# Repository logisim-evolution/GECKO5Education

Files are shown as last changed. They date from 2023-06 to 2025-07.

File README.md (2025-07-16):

# GECKO5Modular

The Gecko5Modular is a new take on an open hardware educational platform. The ideas
of the Gecko5Modular are based on the open hardware [ULX3S](https://github.com/emard/ulx3s) board,
the [Gecko4Education](https://gecko-wiki.ti.bfh.ch/) line of boards, and the recently developed 
[Leguan development board](https://leguan.ti.bfh.ch/).

3D preview:

TOP

This is a small (60.6x100 mm) standalone FPGA board 
for education, research and general purpose. It's open source and 
open hardware. It continues my line of educational boards used in the
past for teaching and research projects.

# Developer's guide
Detailed information how to use the board can be found [here](https://gecko5education.ti.bfh.ch).

# Production
The prototypes for these boards were produced and mounted by [Eurocircuits](https://www.eurocircuits.com/).

# Financement
The prototypes for these board (V1.0 and V1.1) were financed by the [computer architecture lab](https://www.epfl.ch/labs/lap/) of [EPFL](https://www.epfl.ch). Version V1.2 and the CPU-addon was financed by the [HuCE-microlab](https://www.bfh.ch/ti/en/research/research-areas/microlab/) of [BFH](https://www.bfh.ch).

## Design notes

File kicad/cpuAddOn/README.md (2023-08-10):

# GECKO5Education CPU-addon

This design can be used with the GECKO5Education or standalone and provides
an educational base for programming related classes.
In case this board is used with the GECKO5Education, the FTDI-chip is automatically
routed to the integrated USB-hub, meaning that you only require one USB-C connection. 
In case of this situation, the USB-C connector of the GECKO5Education is disabled, and all
functionality is provided by the USB-C connector of the CPU-addon board.

# Debugging

This board integrates a [Black Magic Probe](https://black-magic.org/index.html). After production
it needs to be programmed with the DFU-firmware once by an external programmer. After this firmware-
updates can be performed as with the normal Black Magic Probe.

# External connections

This boards integrates an extention connector (32 positions) that provides two 
[PMOD-compatible](https://digilent.com/reference/_media/reference/pmod/pmod-interface-specification-1_2_0.pdf)
interfaces. The different possibilities are listed below:

PMOD1:

|Pin|function1|function2|function3|
|:-:|:---|:---|:---|
|1  |GPIO |SPI6nCS  |I2S1_WS  |
|2  |GPIO |SPI6MOSI |I2S1_SDO |
|3  |GPIO |SPI6MISO |I2S1_SDI |
|4  |GPIO |SPI6SCK  |I2S1_CK  |
|7  |GPIO |EXTI5 | |
|8  |GPIO |EXTI6 | |
|9  |GPIO |SCL4 | |
|10 |GPIO |SDA4 | |

PMOD2:

|Pin|function1|function2|function3|
|:-:|:---|:---|:---|
|1  |GPIO |CTS2 | |
|2  |GPIO |TX2 | |
|3  |GPIO |RX2 | |
|4  |GPIO |RTS2 | |
|7  |GPIO |EXTI13 | |
|8  |GPIO |ADC1_2_3 |EXTI0 |
|9  |GPIO |ADC1_2_3 |EXTI1 |
|10 |GPIO |ADC3 |EXTI10 |

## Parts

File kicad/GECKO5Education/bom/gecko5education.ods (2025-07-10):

Id | Designator | Footprint | Quantity | Designation | digikey:
1 | C34,C33 | C_0402_1005Metric | 2 | 9pF
2 | Y1 | Crystal_SMD_2012-2Pin_2.0x1.2mm | 1 | RT2012-32.768-9-20-EXT-TR | 2151-RT2012-32.768-12.5-EXT-TRCT-ND
3 | U18 | DS1338Z-33&plus_T&R | 1 | DS1338Z-33+T&R | DS1338Z-33+T&RCT-ND
4 | BT1 | BatteryHolder_Keystone_2998_1x6.8mm | 1 | Battery_Cell | 36-2998-ND
5 | D14,D78,D100,D86,D24,D88,D6,D97,D44,D25,D26,D90,D46,D10,D33,D53,D96,D63,D7,D36,D65,D73,D83,D50,D37,D32,D29,D11,D89,D76,D112,D117,D8,D98,D94,D80,D91,D57,D48,D9,D67,D3,D12,D28,D42,D27,D77,D56,D71,D16,D114,D39,D40,D49,D105,D20,D22,D109,D41,D52,D69,D45,D2,D47,D92,D121,D58,D87,D62,D23,D61,D106,D30,D70,D4,D93,D116,D72,D119,D110,D54,D85,D43,D21,D35,D5,D81,D111,D59,D107,D38,D17,D102,D99,D118,D51,D108,D31,D19,D95,D120,D64,D74,D75,D104,D55,D68,D66,D15,D84,D103,D60,D79,D113,D18,D115,D13,D34,D101,D82 | EAST1616RGBB2 | 120 | EAST1616RGBB2 | 1080-1551-2-ND
6 | C15,C19,C16,C22,C21,C13,C10,C17,C32,C11,C31,C12,C20,C14,C18,C7,C8,C4,C3,C2,C1,C29 | C_0402_1005Metric | 22 | 0.1uf
7 | R38,R44,R37,R43,R40,R42,R39,R41 | R_0402_1005Metric | 8 | 130R
8 | R22 | R_0402_1005Metric | 1 | 1k1
9 | R89,R91,R70,R83,R80,R77,R68,R86,R73,R85,R76,R67,R82,R65,R71,R88,R79,R74,R64,R92 | R_0402_1005Metric | 20 | 698R
10 | R81,R78,R93,R66,R72,R87,R75,R84,R90,R69 | R_0402_1005Metric | 10 | 274R
11 | Q15,Q6,Q4,Q16,Q17,Q3,Q1,Q11,Q13,Q2,Q10,Q14,Q8,Q12,Q7,Q9,Q5 | SOT-23 | 17 | BC807 | BC807-25-TPMSTR-ND
12 | R24,R30,R11,R61,R46,R12,R63,R26,R62,R4,R23,R45,R1,R14,R15,R47,R29,R25,R2,R13,R16,R60,R7,R10,R28,R27 | R_0402_1005Metric | 26 | 10k
13 | U4,U5 | SOT815-1_3.5_5.5_0.85 | 2 | 74HC154BQ,118 | 1727-6583-1-ND
14 | R5 | R_0402_1005Metric | 1 | 12k
15 | U12 | LTC-4627Jx | 1 | LTC-4627JR | 160-1550-5-ND
16 | R55,R35,R48,R52,R57,R49,R54,R34,R53,R36,R50,R51,R59,R32,R6,R58,R56,R33 | R_0402_1005Metric | 18 | 1k
17 | J3 | PinSocket_1x06_P2.54mm_Horizontal | 1 | Conn_01x06_Socket | SAM1225-06-ND
18 | C25,C26,C28,C24 | C_0603_1608Metric | 4 | C1608X5R0J106M080AB | 445-4112-2-ND
19 | U13,U14 | SOT-23-5 | 2 | NCP1529A | NCP1529ASNT1GOSTR-ND
20 | X2 | Oscillator_SMD_ECS_2520MV-xxx-xx-4Pin_2.5x2.0mm | 1 | ECS-2520MV-500-BL-TR | 50-ECS-2520MV-500-BL-TRCT-ND
21 | C9 | C_0402_1005Metric | 1 | 3u3 | 399-C0402C335M7PAC7867TR-ND
22 | X3 | OSCCC700X500X180-4N | 1 | CB3LV-3I-74M2500 | 110-CB3LV-3I-74M250000CT-ND
23 | L1,L2 | INDUCTOR | 2 | LQM2HPN2R2MJ0L | 490-6700-1-ND
24 | U10 | SOT-23-5 | 1 | LP5907MFX-1.8 | 296-41463-1-ND
25 | SW6 | SW_B3U-1000P_OMR | 1 | B3U-1000P[] | SW1020CT-ND
26 | SW1,SW5,SW2,SW4,SW3 | pushbutton | 5 | SW_Push | 450-1759-1-ND
27 | C23,C27 | C_0402_1005Metric | 2 | 18p
28 | U8 | SOT-23-5 | 1 | LP5907MFX-2.5 | 296-40356-1-ND
29 | U1 | SOIC-8_3.9x4.9mm_P1.27mm | 1 | 93C46C-I/SN | 93C46C-I/SN-ND
30 | R8 | R_0402_1005Metric | 1 | 510R
31 | R117,R116 | R_0402_1005Metric | 2 | 5k1
32 | X4 | Oscillator_SMD_ECS_2520MV-xxx-xx-4Pin_2.5x2.0mm | 1 | ECS-2520MV-240-BL-TR | 50-ECS-2520MV-120-BL-TRCT-ND
33 | U17 | SOP50P490X110-11N | 1 | MAX11102AUB/V+ | MAX11102AUB/V+-ND
34 | D123,D122,D1,D124 | D_0402_1005Metric | 4 | SBA0530Q_R1_00001 | 3757-SBA0530Q_R1_00001CT-ND
35 | J2 | HDMI_A_Molex_208658-1001_Horizontal | 1 | HDMI_A | 900-2086581001CT-ND
36 | U15 | NX3DV42GU,115 | 1 | NX3DV42GU,115 | 568-12388-1-ND | NX3DV42GU,115
37 | U3 | QFP50P1200X1200X120-64N | 1 | TFP410PAP | 296-12666-ND
38 | J1 | USB_C_Receptacle_Molex_105450-0101 | 1 | USB_C_Receptacle | WM12856CT-ND
39 | R111 | R_0402_1005Metric | 1 | 150k
40 | SW9 | dipswitch | 1 | SW_DIP_x08 | 1-1825058-9-ND
41 | R18,R19,R20 | R_0402_1005Metric | 3 | 15k
42 | J4 | PinSocket_2x09_P2.54mm_Horizontal | 1 | Conn_02x09_Odd_Even | S5562-ND
43 | U6 | Lattice_caBGA-381_17.0x17.0mm_Layout20x20_P0.8mm_Ball0.4mm_Pad0.4mm_NSMD | 1 | LFE5U-85F-6BG381x | LFE5U-85F-6BG381C
44 | U11 | SOP-8_5.28x5.23mm_P1.27mm | 1 | MX25R3235FM2IL0 | 1092-1200-ND
45 | X1 | Oscillator_SMD_ECS_2520MV-xxx-xx-4Pin_2.5x2.0mm | 1 | ECS-2520MV-120-BL-TR | 50-ECS-2520MV-120-BL-TRCT-ND
46 | R112,R113 | R_0402_1005Metric | 2 | 100k
47 | U16 | SOT65P280X100-8N | 1 | LTC2632CTS8-LZ12TRMPBF | 505-LTC2632CTS8-LZ12#TRMPBFCT-ND
48 | R21 | R_0402_1005Metric | 1 | 4k7
49 | R110 | R_0402_1005Metric | 1 | 680k
50 | S1 | SW_JS5208 | 1 | JS5208 | EG4561-ND
51 | U7 | SOIC-8_5.23x5.23mm_P1.27mm | 1 | W25Q128JVS | W25Q128JVSIQCT-ND
52 | U9 | tf_bga_54L_8x8 | 1 | IS42VM16160k-75BLI | 706-1313-ND
53 | R3 | R_0402_1005Metric | 1 | 2k2
54 | U2 | QFN-64-1EP_9x9mm_P0.5mm_EP4.35x4.35mm | 1 | FT2232HQ | 768-1025-1-ND
55 | J5 | SAMTEC_QSE-020-01-X-D-A | 1 | QSE-020-01-XXX-D | 612-QSE-020-01-F-D-A-CT-ND

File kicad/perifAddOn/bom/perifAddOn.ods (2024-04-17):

Id | Designator | Footprint | Quantity | Designation | Digikey:
1 | R2,R1 | R_0402_1005Metric | 2 | 5k1
2 | C19,C20,C8,C4,C5,C23,C14,C2,C26,C6,C13,C15,C22,C1,C7,C24 | C_0402_1005Metric | 16 | 100n
3 | C16,C17 | C_0402_1005Metric | 2 | 9pF
4 | R22 | R_0402_1005Metric | 1 | 768R
5 | U5 | ESP32-C3-MINI-1_EXP | 1 | ESP32-C3-MINI-1-N4 | 1965-ESP32-C3-MINI-1-N4CT-ND
6 | SW1,SW2,SW3 | SW_B3U-1000P_OMR | 3 | B3U-1000P[] | SW1020CT-ND
7 | C21,C25 | C_0402_1005Metric | 2 | 1uF
8 | R5,R18,R10,R24,R20,R21,R4,R17,R9,R12,R3,R19,R11,R6 | R_0402_1005Metric | 14 | 10k
9 | J4 | PinHeader_2x15_P2.54mm_Horizontal | 1 | 302-R301 | ED10539-ND
10 | Y1 | Crystal_SMD_2012-2Pin_2.0x1.2mm | 1 | RT2012-32.768-9-20-EXT-TR | 2151-RT2012-32.768-9-20-EXT-TRCT-ND
11 | J2 | MOLEX_105450-0101 | 1 | 105450-0101 | WM12856CT-ND
12 | U2 | D14 | 1 | SN74HC266DR | 296-31804-1-ND
13 | R23 | R_0402_1005Metric | 1 | 330R
14 | U4 | SOT-23-5 | 1 | NCP1529A | NCP1529ASNT1GOSCT-ND
15 | R16,R15,R14 | R_0402_1005Metric | 3 | 100k
16 | C12,C11,C18,C3,C9 | C_0603_1608Metric | 5 | C1608X5R0J106M080AB | 445-4112-1-ND
17 | R7 | R_0402_1005Metric | 1 | 680k
18 | J5 | PinSocket_2x15_P2.54mm_Horizontal | 1 | PPPC152LJBN-RC | S5568-ND
19 | U7 | TSSOP20_TOS | 1 | TC7MBL3245CFTEL | TC7MBL3245CFT(EL)CT-ND
20 | L1 | LQM2HPN2R2MJ0L | 1 | LQM2HPN2R2MJ0L | 490-6700-2-ND
21 | R13 | R_0402_1005Metric | 1 | 12k
22 | J3 | AMPHENOL_GTFP08431BEU | 1 | GTFP08431BEU | GTFP08431BEUTR-ND
23 | X1 | Oscillator_SMD_ECS_2520MV-xxx-xx-4Pin_2.5x2.0mm | 1 | ECS-2520MV-240-BL-TR | 50-ECS-2520MV-240-BL-TRCT-ND
24 | D1 | LED_APHBM2012SURKCGKC | 1 | APHBM2012SURKCGKC | 754-1093-1-ND
25 | U6 | QFN36_6X6MC_MCH | 1 | USB2244-AEZG-06 | USB2244-AEZG-06-ND
26 | R8 | R_0402_1005Metric | 1 | 150k
27 | C10 | C_0402_1005Metric | 1 | 18p
28 | U3 | QFN36_6X6MC_MCH | 1 | USB2513B-AEZC | USB2513B-AEZC-ND
29 | U1 | SOT26_DIO | 1 | AP2281-3WG-7 | AP2281-3WG-7DICT-ND
30 | J1 | SAMTEC_QTE-020-01-X-D-A | 1 | QTE-020-01-X-D-A | SAM8846-ND

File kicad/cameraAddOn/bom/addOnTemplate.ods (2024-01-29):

Id | Designator | Footprint | Quantity | Designation | Digikey:
1 | J5 | PinHeader_2x04_P2.54mm_Horizontal | 1 | Conn_01x08 | 609-3344-ND
2 | U6 | SOT-23-5 | 1 | NCP1529A | NCP1529ASNT1GOSCT-ND
3 | R6 | R_0402_1005Metric | 1 | 150k
4 | R5 | R_0402_1005Metric | 1 | 680k
5 | L1 | LQM2HPN2R2MJ0L | 1 | LQM2HPN2R2MJ0L | 490-6700-1-ND
6 | C26,C13,C20,C11,C23 | C_0603_1608Metric | 5 | C1608X5R0J106M080AB | 445-4112-1-ND
7 | C17 | C_0402_1005Metric | 1 | 18p
8 | U3 | SOT26_DIO | 1 | AP2281-3WG-7
9 | J12 | USB_A_Molex_67643_Horizontal | 1 | USB_B | WM4078-ND
10 | J3 | AMPHENOL_GTFP08431BEU | 1 | GTFP08431BEU | GTFP08431BEUCT-ND
11 | C25,C8,C22,C5,C9,C16,C24,C21,C14,C12,C15,C10,C33,C32,C35,C34,C1,C4 | C_0402_1005Metric | 18 | 0.1uf
12 | C19,C6,C7,C18 | C_0402_1005Metric | 4 | 9pF
13 | R19,R21,R20 | R_0402_1005Metric | 3 | 100k
14 | Y2,Y1 | Crystal_SMD_2012-2Pin_2.0x1.2mm | 2 | RT2012-32.768-9-20-EXT-TR | 2151-RT2012-32.768-9-20-EXT-TRCT-ND
15 | R14,R34,R25,R35,R9,R17,R16,R10,R28,R11,R30,R15,R29,R27,R31 | R_0402_1005Metric | 15 | 10k
16 | R2,R1 | R_0402_1005Metric | 2 | 27R
17 | R26 | R_0402_1005Metric | 1 | 510R
18 | SW3,SW1 | SW_B3U-1000P_OMR | 2 | B3U-1000P[] | SW1020CT-ND
19 | R32 | R_0402_1005Metric | 1 | 768R
20 | C3,C2 | C_0402_1005Metric | 2 | 47pF
21 | BT1 | BatteryHolder_Keystone_1060_1x2032 | 1 | Battery_Cell | 36-1060-ND
22 | U2 | DS1338Z-33&plus_T&R | 1 | DS1338Z-33+T&R | DS1338Z-33+T&RCT-ND
23 | X1 | Oscillator_SMD_ECS_2520MV-xxx-xx-4Pin_2.5x2.0mm | 1 | ECS-2520MV-240-BL-TR | 50-ECS-2520MV-240-BL-TRCT-ND
24 | D2 | LED_APHBM2012SURKCGKC | 1 | APHBM2012SURKCGKC | 754-1093-1-ND
25 | R18 | R_0402_1005Metric | 1 | 12k
26 | U5 | ESP32-C3-MINI-1_EXP | 1 | ESP32-C3-MINI-1-N4 | 1965-ESP32-C3-MINI-1-N4CT-ND
27 | R33 | R_0402_1005Metric | 1 | 330R
28 | U4 | QFN36_6X6MC_MCH | 1 | USB2513B-AEZC | USB2513B-AEZC-CT-ND
29 | J1 | USB_Micro-AB_Molex_47590-0001 | 1 | USB_B_Micro | WM17144CT-ND
30 | R4,R3 | R_0402_1005Metric | 2 | 4k7
31 | U1 | QFN-20-1EP_4x4mm_P0.5mm_EP2.5x2.5mm | 1 | FT231XQ | 768-1128-1-ND
32 | J2 | PinSocket_2x09_P2.54mm_Horizontal | 1 | Conn_02x09_Odd_Even | S5523-ND
33 | J4 | HDMI_A_Molex_208658-1001_Horizontal | 1 | HDMI_A | 900-2086581001CT-ND
34 | U7 | QFP50P1200X1200X120-64N | 1 | SII164CTG64 | 220-2189-ND
35 | J9,J8,J7,J11 | PinHeader_1x08_P2.54mm_Vertical | 4 | Conn_01x08 | 732-5321-ND
36 | J6 | PinHeader_2x18_P2.54mm_Vertical | 1 | Conn_02x18_Odd_Even | S2011EC-18-ND

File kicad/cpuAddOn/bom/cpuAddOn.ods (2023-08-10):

Id | Designator | Footprint | Quantity | Designation | Digikey:
1 | U4 | D14 | 1 | SN74HC266DR | 296-31804-1-ND
2 | SW2,SW5,SW3,SW1,SW4 | SW_B3U-1000P_OMR | 5 | B3U-1000P | SW1020CT-ND
3 | R7,R3,R4 | R_0402_1005Metric | 3 | 100k
4 | C40,C41,C31 | C_0402_1005Metric | 3 | 2.2uF
5 | C23,C24,C25,C53,C30,C36,C29,C32,C26,C54,C21 | C_0402_1005Metric | 11 | 1uF
6 | C8,C15,C19,C46,C33,C42,C45,C44,C55,C12,C43,C9,C13,C22,C39,C48,C51,C52,C14,C20,C35,C17,C38,C50,C37,C10,C34,C6,C7,C49,C47,C11,C16,C18 | C_0402_1005Metric | 34 | 100nF
7 | R36,R40,R41,R38,R37,R42,R39,R35 | R_0402_1005Metric | 8 | 62R
8 | U10 | 21-0140L_T3255-4_MXM | 1 | MAX9867ETJ+ | MAX9867ETJ+-ND
9 | U8 | SOIC127P599X175-8N | 1 | ISO1044BD | 296-ISO1044BD-ND
10 | U7 | TSOP-II-54_22.2x10.16mm_P0.8mm | 1 | AS4C16M16SA-6TAN | 1450-1251-ND
11 | R17,R25,R18,R28,R32,R31,R30,R33,R10,R11,R16,R15,R12,R21,R24,R26,R13,R9 | R_0402_1005Metric | 18 | 10k
12 | D2,D1 | LED_APHBM2012SURKCGKC | 2 | APHBM2012SURKCGKC | 754-1093-1-ND
13 | C27,C28 | C_0402_1005Metric | 2 | 220nF
14 | U13 | PQFN50P300X250X97-14N | 1 | ICM-42605 | 1428-1152-1-ND
15 | U15 | SON65P200X240X70-6N | 1 | TCS34003FNM | TCS34003FNMCT-ND
16 | R34 | R_0402_1005Metric | 1 | 47R
17 | U9 | RVA16_2P14X2P14_TEX | 1 | TS3A227ERVAR | 296-38654-1-ND
18 | R2,R1 | R_0402_1005Metric | 2 | 5.1k
19 | U6 | LQFP-144_20x20mm_P0.5mm | 1 | STM32H743ZIT6 | 497-17721-ND
20 | C5,C1,C4,C3 | C_0603_1608Metric | 4 | C1608X5R0J106M080AB | 445-4112-1-ND
21 | J3 | PinHeader_1x05_P2.54mm_Horizontal | 1 | Conn_01x05_Pin | 2057-PH1RB-05-UA-ND
22 | R29 | R_0402_1005Metric | 1 | 2.2k
23 | R27 | TRIM_3352T-1-103LF | 1 | 3352T-1-103LF | 3352T-103LF-ND
24 | R19,R22 | R_0402_1005Metric | 2 | 768R
25 | J2 | MOLEX_105450-0101 | 1 | 105450-0101 | WM12856CT-ND
26 | L2 | L_0402_1005Metric | 1 | LRC0402CS2N2GV001T | 712-LRC0402CS2N2GV001TCT-ND
27 | R8 | R_0402_1005Metric | 1 | 12k
28 | U11 | SOT-23-5 | 1 | LP5907MFX-1.8 | 296-41463-1-ND
29 | X2 | Oscillator_SMD_ECS_2520MV-xxx-xx-4Pin_2.5x2.0mm | 1 | ECS-2520MV-080-BM-TR | 50-ECS-2520MV-080-BM-TRCT-ND
30 | J5 | TE_2311765-1 | 1 | TE_2311765-1 | 2311765-2-ND
31 | S1 | JS5208 | 1 | JS5208 | EG4561-ND
32 | L1 | LQM2HPN2R2MJ0L | 1 | LQM2HPN2R2MJ0L | 490-6700-1-ND
33 | R14 | R_0402_1005Metric | 1 | 1.5k
34 | R20,R23 | R_0402_1005Metric | 2 | 330R
35 | J4 | CUI_SJ-3551B-MSMT-TR-67 | 1 | SJ-3551B-MSMT-TR-67 | 102-6037-1-ND
36 | PS1 | RFM-0505S | 1 | RFM-0505S | 945-3159-ND
37 | BT1 | BatteryHolder_Keystone_1060_1x2032 | 1 | Keystone_1060 | 36-1060-ND
38 | U16 | HDSM-433C | 1 | HDSM-433C | 516-3498-1-ND
39 | J7 | PinSocket_2x16_P2.54mm_Horizontal | 1 | Conn_02x16_Odd_Even | S5569-ND
40 | U3 | UFQFPN-48_7X7X0P55MM | 1 | STM32F103CBU6 | 497-17381-ND
41 | SD1 | sdcard | 1 | 104031-0811 | WM6357CT-ND
42 | A1 | PQFN50P200X200X80-10N | 1 | LPS22HBTR | 497-16265-1-ND
43 | U14 | SHT4X | 1 | SHT40-AD1B-R2 | 1649-SHT40-AD1B-R2CT-ND
44 | U5 | SOT26_DIO | 1 | AP2281-3WG-7 | AP2281-3WG-7DICT-ND
45 | C2 | C_0402_1005Metric | 1 | 18pF
46 | U1 | QFN36_6X6MC_MCH | 1 | USB2513B-AEZC | USB2513B-AEZC-ND
47 | U2 | SOT-23-5 | 1 | NCP1529A | NCP1529ASNT1GOSCT-ND
48 | R6 | R_0402_1005Metric | 1 | 150k
49 | U12 | SOP-8_5.28x5.23mm_P1.27mm | 1 | MX25R3235FM2IL0 | MX25R3235FM2IL0-ND
50 | R5 | R_0402_1005Metric | 1 | 680k
51 | X1 | Oscillator_SMD_ECS_2520MV-xxx-xx-4Pin_2.5x2.0mm | 1 | ECS-2520MV-240-BL-TR | 50-ECS-2520MV-240-BL-TRCT-ND
52 | J1 | SAMTEC_QTE-020-01-X-D-A | 1 | QTE-020-01-F-D-A | SAM8846-ND
53 | Y1 | Crystal_SMD_0603-2Pin_6.0x3.5mm | 1 | RT2012-32.768-9-20-EXT-TR | 2151-RT2012-32.768-9-20-EXT-TRCT-ND
54 | C57,C56 | C_0402_1005Metric | 2 | 9pF

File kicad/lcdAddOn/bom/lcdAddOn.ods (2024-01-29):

Id | Designator | Footprint | Quantity | Designation | Digikey:
1 | U1 | SSOP20_MC_MCH | 1 | AR1021-I/SS | AR1021-I/SS-ND
2 | C3 | C_0402_1005Metric | 1 | 100nF
3 | R4,R2,R3,R1 | R_0402_1005Metric | 4 | 2E
4 | R5 | R_0402_1005Metric | 1 | 20k
5 | C2,C1 | C_0402_1005Metric | 2 | 10pF
6 | J2 | CONN_62684-402100ALF_AMP | 1 | 62684-402100ALF | 609-1200-1-ND
7 | J1 | SAMTEC_QTE-020-01-X-D-A | 1 | QTE-020-01-F-D-A | SAM8846-ND
8 | SW1,SW2,SW3 | pushbutton | 3 | SW_Push | 450-1759-1-ND

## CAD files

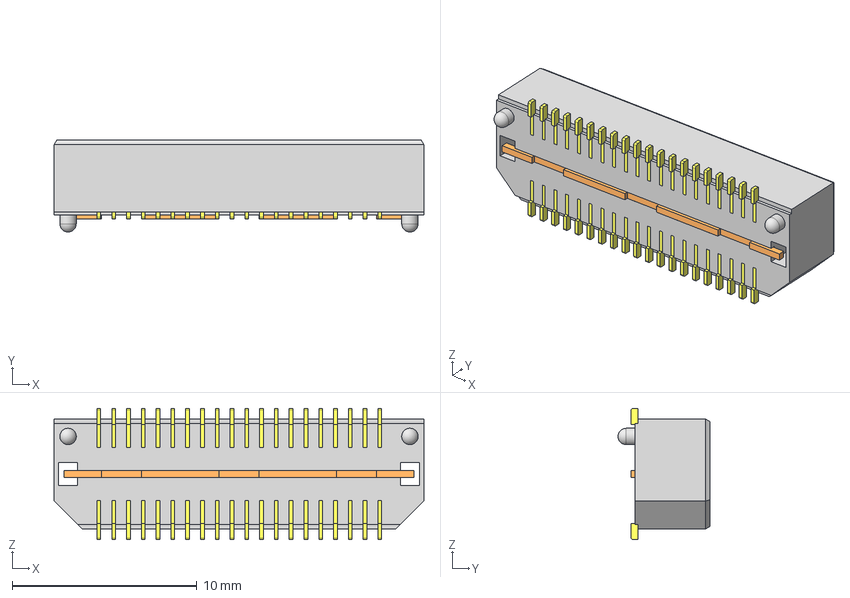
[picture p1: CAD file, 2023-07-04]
kicad/cameraAddOn/3DModels/QTE-020-01-X-D-A.step
20.0 x 4.98 x 7.11 mm
QTE-T-1G1-01_imp
PT-1S39-01(020-01-D)
QTE-020-01-D-At

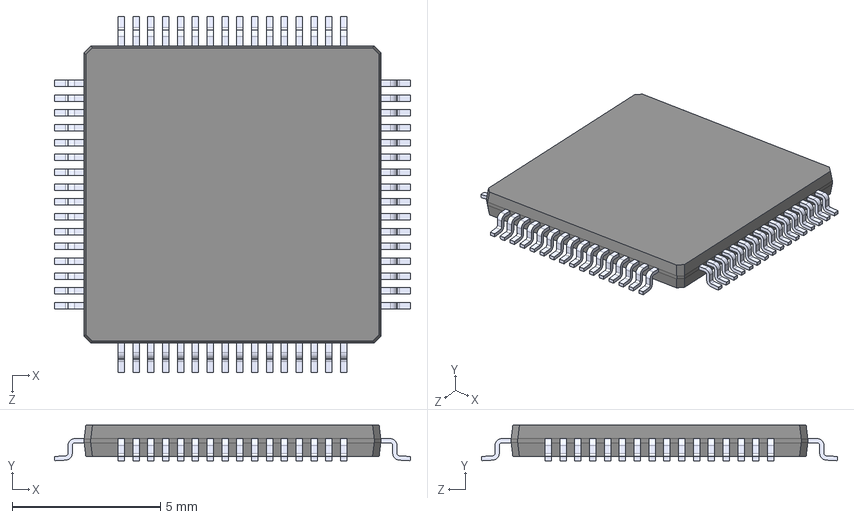
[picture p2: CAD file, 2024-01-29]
kicad/GECKO5Education/3DModels/ATSAMD51J20A-AU.STEP
12.0 x 1.20 x 12.0 mm

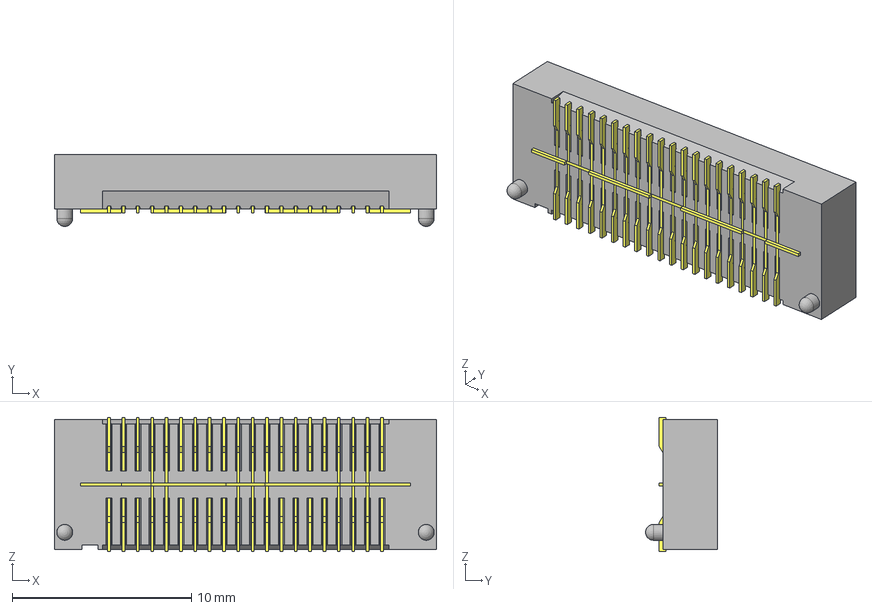
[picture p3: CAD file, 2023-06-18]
kicad/GECKO5Education/QSE-020-01-F-D-A.stp
21.3 x 4.01 x 7.49 mm
QSE-C-126-21-020-D-S
QSE-T-1G2-01-020
QSE-020-01-F-D-A-S_terminal

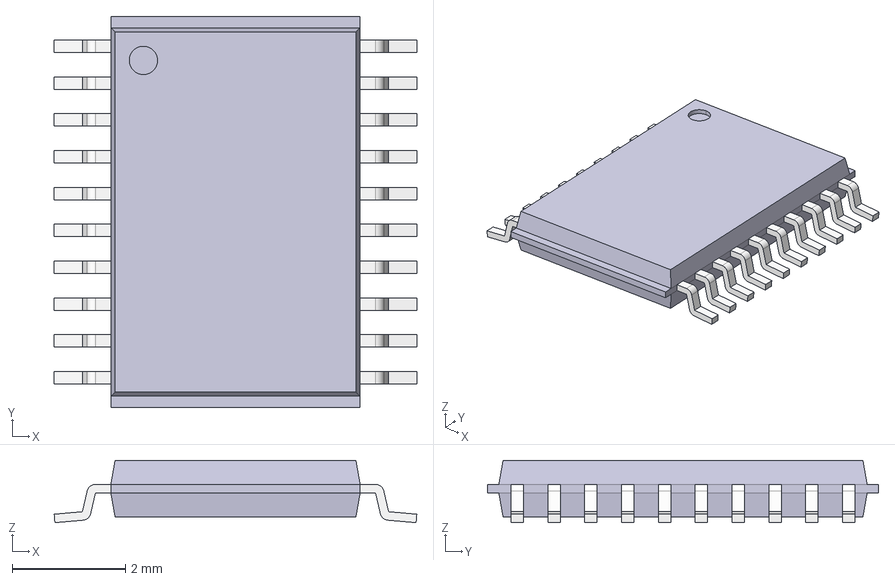
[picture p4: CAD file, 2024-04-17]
kicad/perifAddOn/3DModels/TSSOP20_z90.stp
6.40 x 6.90 x 1.10 mm

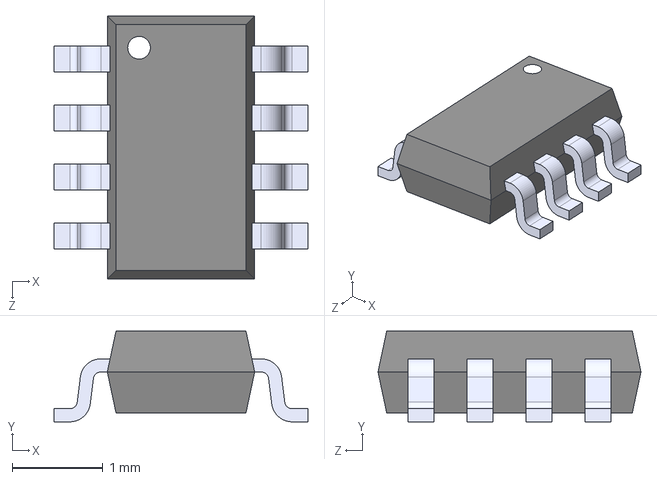
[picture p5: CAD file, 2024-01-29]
kicad/GECKO5Education/3DModels/LTC2632CTS8-LZ12#TRMPBF.STEP
2.80 x 1.00 x 2.90 mm

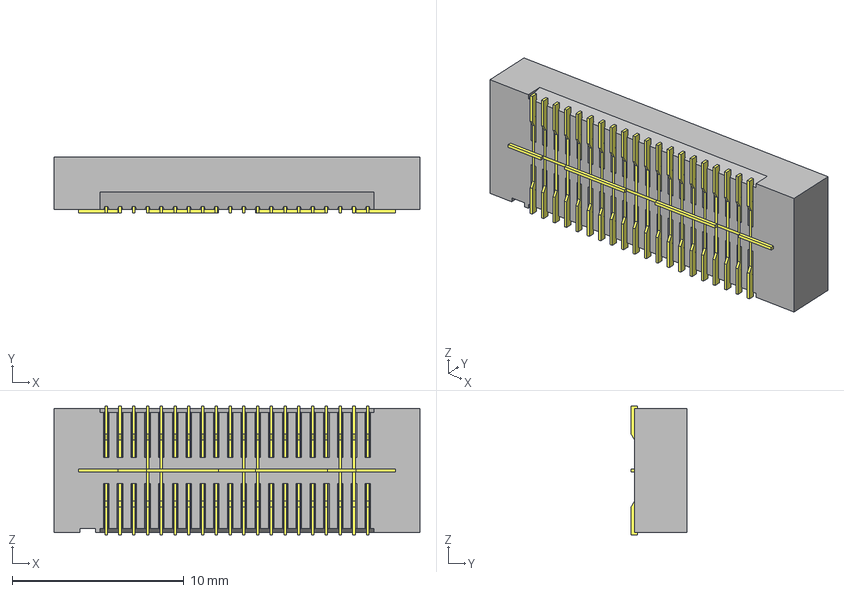
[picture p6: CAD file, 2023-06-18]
kicad/GECKO5Education/QSE-020-01-F-D.stp
21.3 x 3.25 x 7.49 mm
QSE-C-126-21-020-D-S
QSE-T-1G2-01-020
QSE-020-01-F-D-S_terminal

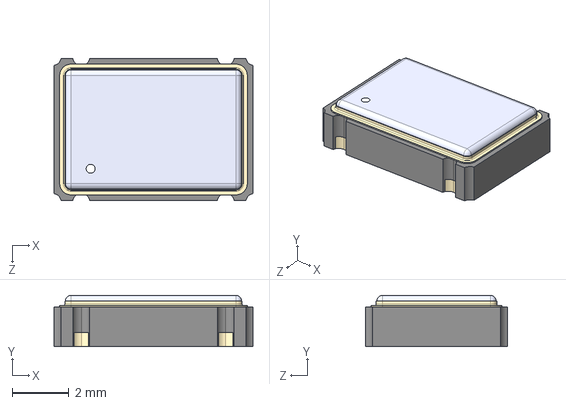
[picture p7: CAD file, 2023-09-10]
kicad/GECKO5Education/3DModels/CB3LV-3I-74M2500.step
7.00 x 1.80 x 5.00 mm

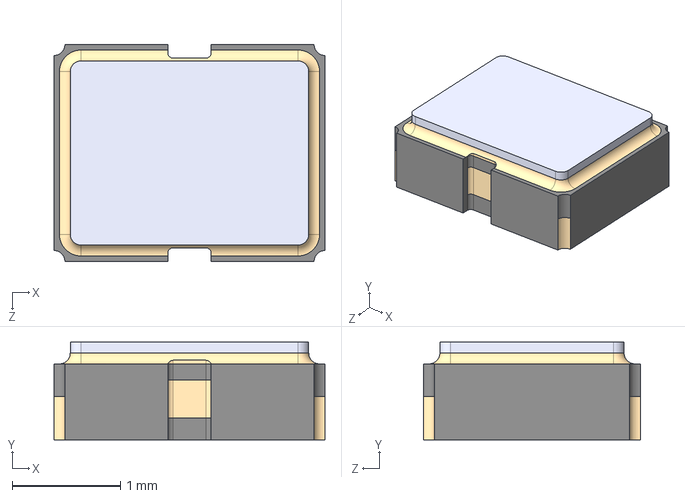
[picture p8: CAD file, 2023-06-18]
kicad/GECKO5Education/3DModels/ECS-2520MV-500-BL-TR--3DModel-STEP-269445.STEP
2.50 x 0.9 x 2.00 mm

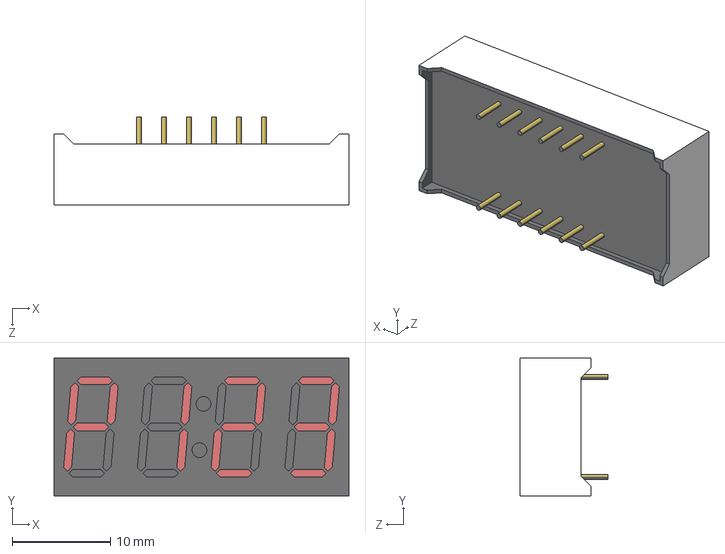
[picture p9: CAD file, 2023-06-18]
kicad/GECKO5Education/3DModels/7 segment1.STEP
30.0 x 14.0 x 8.93 mm

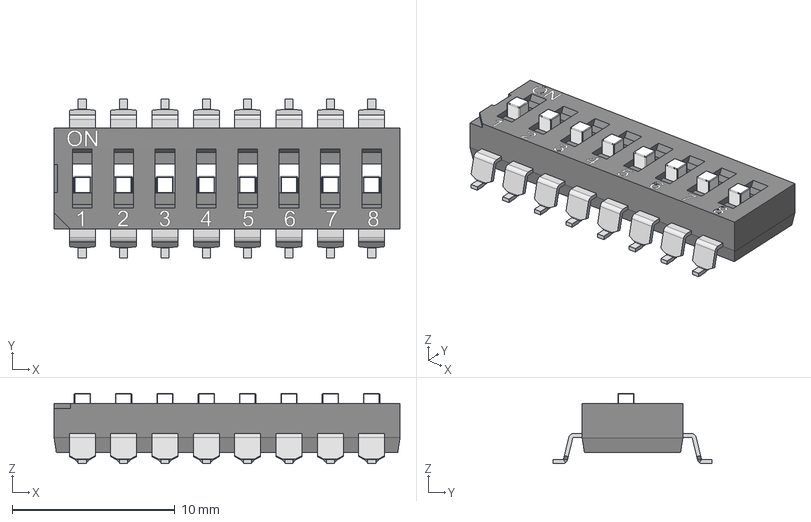
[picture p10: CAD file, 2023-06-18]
kicad/GECKO5Education/3DModels/SMD DIP SWITCH 8P.step
21.3 x 9.80 x 4.32 mm

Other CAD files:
kicad/perifAddOn/3DModels/XZCMEDGCBD110W--3DModel-STEP-56544.STEP
kicad/perifAddOn/3DModels/APHBM2012LSURKCGKC--3DModel-STEP-56544.STEP
kicad/perifAddOn/3DModels/QTE-020-01-X-D-A.step
kicad/perifAddOn/3DModels/D0014A.stp
kicad/perifAddOn/3DModels/21-0140L_T3255-4_MXM.step
kicad/perifAddOn/3DModels/2998TR--3DModel-STEP-630548.STEP
kicad/GECKO5Education/3DModels/1054500101.stp
kicad/GECKO5Education/3DModels/MAX11666AUB_V+.STEP
kicad/GECKO5Education/3DModels/QFN_H-56Q-TRAY_FTD.step
kicad/cpuAddOn/3DModels/104031-0811.stp
kicad/cpuAddOn/3DModels/105450-0101.step
kicad/cpuAddOn/3DModels/21-0140L_T3255-4_MXM.step
kicad/cpuAddOn/3DModels/2311765-1.stp
kicad/cpuAddOn/3DModels/2998TR--3DModel-STEP-630548.STEP
kicad/cpuAddOn/3DModels/3352T-1-103LF.step
kicad/cpuAddOn/3DModels/APHBM2012LSURKCGKC--3DModel-STEP-56544.STEP
kicad/cpuAddOn/3DModels/B0505S-1WR2.step
kicad/cpuAddOn/3DModels/D0014A.stp
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

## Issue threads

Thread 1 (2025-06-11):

[Feature suggestion] Providing the LPF constraints file

CyberFox001, 2025-06-11:
Hello,

First, a big thanks for your magnificent board.

As this board use the `LFE5U-85F` FPGA, it would be nice to provide the LPF constraints file adapted to the GECKO5Education board.
It would let users use the `nextpnr-ecp5` and the OSS CAD Suite to build a bitstream for the GECKO5Education.

BFH-ktt1, 2025-06-11:
Here you go:
[gecko5.zip](https://github.com/user-attachments/files/20685172/gecko5.zip)

By the way, you can also mount smaller ecp5's, the board is designed to be pin-compatable.

CyberFox001, 2025-06-11:
Thank you. Does the GECKO5Education pin-compatible with the ULX3S ?

CyberFox001, 2025-06-12:
Are you the author of this constraint file ? What are its license ?

BFH-ktt1, 2025-06-12:
> Are you the author of this constraint file ? What are its license ?

Yes, and you can use it as you like (so no license), of course with no guarantee, etc. etc.
I give it as template to my students that are working on the board.

CyberFox001, 2025-06-15:
Ok. Thank you very much.

I have seen a small mistake in the constraint file:
- The output `rgbRow` control the column in the LED matrix
- It's the outputs `red`, `green` and `blue` who control rows of the LED matrix

At least, from what I can see on the electronic schematics and on the printed circuit.

PS: I'm making my diploma work on the Gecko5Education.

BFH-ktt1, 2025-07-28:
@CyberFox001 , in a sense you are right. It all depends from which side you look at it. When we look at pin T1, from the FPGA this is the Rx, however, from the FTDI it is the Tx. This is a standard point for confusion. I would be very interested if you have some idea how to "fix" this.

CyberFox001, 2025-07-28:
As we use the inputs names of the constraint file in a HDL circuit, it make sense to use the FPGA point of view. I think.

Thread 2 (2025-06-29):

In the README, link to Gecko4Eudacation is not publicly reachable

CyberFox001, 2025-06-29:
Hello,

In the README, their is a link to the Gecko4Education line of beard. But when I follow this link, I get an error message:

> Forbidden
> Please connect to the BFH VPN service to access this resource.

maehne, 2025-06-30:
Indeed, we are aware of the problem. The documentation site is currently only reachable to students and collaborators of BFH. The documentation needs to be migrated to a new platform. Unfortunately, this effort is currently stalled due to limited resources.

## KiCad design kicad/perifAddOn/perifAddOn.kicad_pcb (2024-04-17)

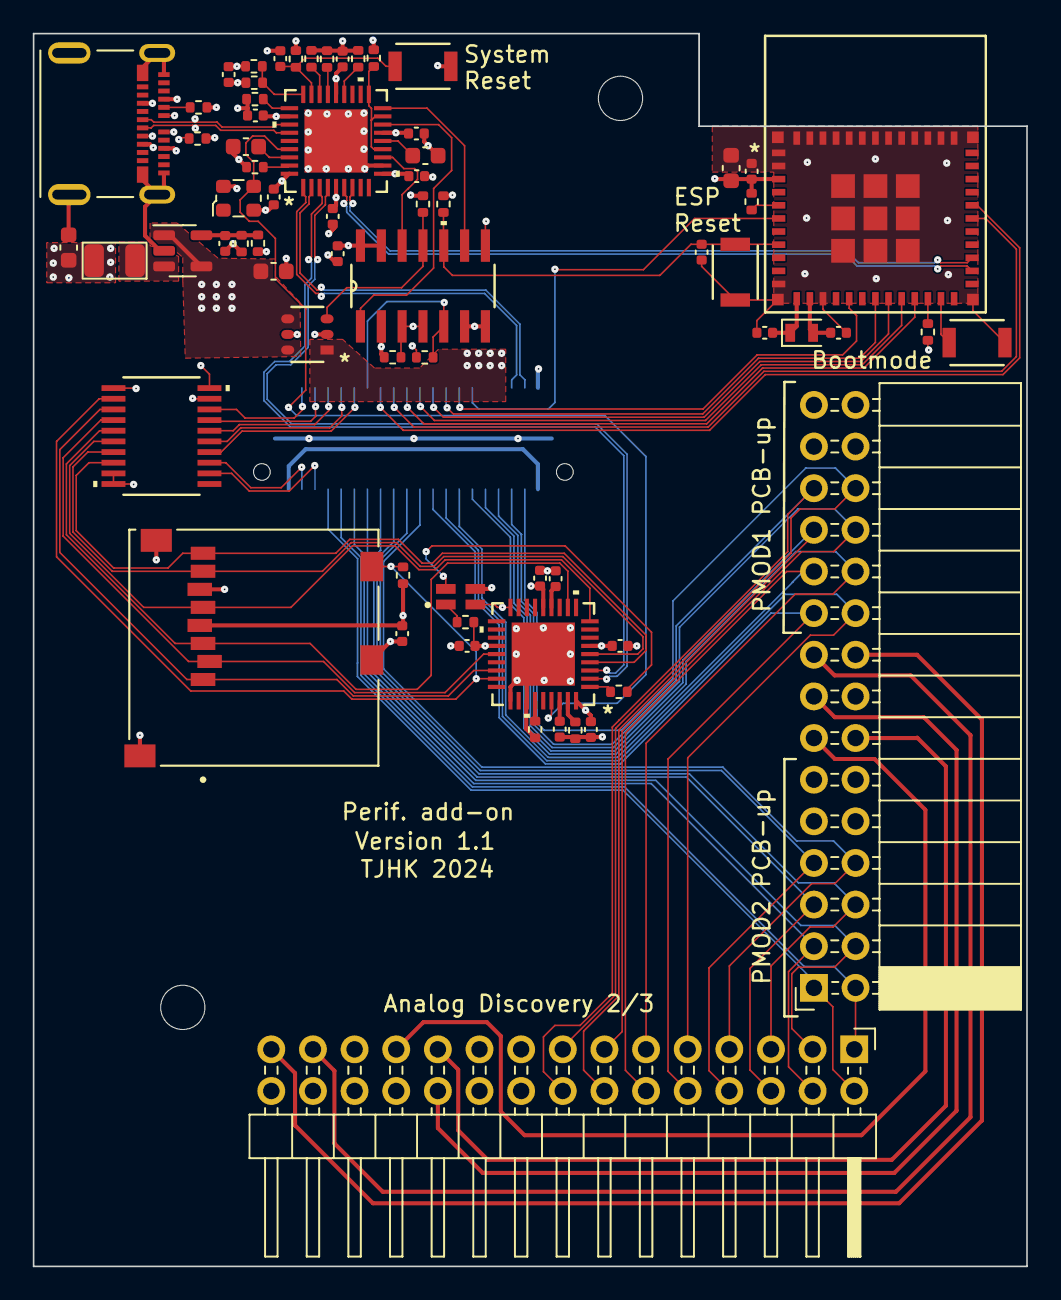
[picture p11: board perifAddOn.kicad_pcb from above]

Board: 4 copper layers, 60.6 x 75.2 mm, 69 parts (1 on the bottom side), 90 nets.

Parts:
C1, C2, C4, C5, C6, C7, C8, C13, C14, C15, C19, C20, C22, C23, C24, C26: 100n; C_0402_1005Metric
C3, C9, C11, C12, C18: C1608X5R0J106M080AB; C_0603_1608Metric
C10: 18p; C_0402_1005Metric
C16, C17: 9pF; C_0402_1005Metric
C21, C25: 1uF; C_0402_1005Metric
D1: APHBM2012SURKCGKC; LED_APHBM2012SURKCGKC
J1: QTE-020-01-X-D-A; SAMTEC_QTE-020-01-X-D-A
J2: 105450-0101; MOLEX_105450-0101
J3: GTFP08431BEU; AMPHENOL_GTFP08431BEU
J4: Conn_02x15_Odd_Even; PinHeader_2x15_P2.54mm_Horizontal
J5: Conn_02x15_Odd_Even; PinSocket_2x15_P2.54mm_Horizontal
L1: LQM2HPN2R2MJ0L
R1, R2: 5k1; R_0402_1005Metric
R3, R4, R5, R6, R9, R10, R11, R12, R17, R18, R19, R20, R21, R24: 10k; R_0402_1005Metric
R7: 680k; R_0402_1005Metric
R8: 150k; R_0402_1005Metric
R13: 12k; R_0402_1005Metric
R14, R15, R16: 100k; R_0402_1005Metric
R22: 768R; R_0402_1005Metric
R23: 330R; R_0402_1005Metric
SW1, SW2, SW3: B3U-1000P[]; SW_B3U-1000P_OMR
U1: AP2281-3WG-7; SOT26_DIO
U2: SN74HC266DR; D14
U3: USB2513B-AEZC; QFN36_6X6MC_MCH
U4: NCP1529A; SOT-23-5
U5: ESP32-C3-MINI-1-N4; ESP32-C3-MINI-1_EXP
U6: USB2244-AEZG-06; QFN36_6X6MC_MCH
U7: TC7MBL3245CFTEL; TSSOP20_TOS
X1: ECS-2520MV-240-BL-TR; Oscillator_SMD_ECS_2520MV-xxx-xx-4Pin_2.5x2.0mm
Y1: RT2012-32.768-9-20-EXT-TR; Crystal_SMD_2012-2Pin_2.0x1.2mm

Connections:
+3.3V: C1.1, C2.1, C4.1, C5.1, C6.1, C7.1, C8.1, C10.1, C11.1, C15.2, C18.1, C20.2, C22.1, C23.1, C24.1, C26.1, J3.4 (VDD), J5.11, J5.12, J5.29, J5.30, L1.2, R3.2, R4.1, R5.1, R6.2, R7.1, R16.2, R17.2, R18.2, R19.2, R22.1, U2.2 (1B), U2.8 (3A), U2.13 (4B), U2.14 (VCC), U3.5 (VDDA33), U3.10 (VDDA33), U3.15 (VDD33), U3.23 (VDD33), U3.29 (VDDA33), U3.36 (VDD33), U5.3 (3V3), U6.6 (VDD33), U6.14 (VDD33), U6.22 (VDD33), U6.36 (VDDA33), U7.20, X1.4 (VDD)
+5V: C9.1, C13.1, J2.A4 (VBUS1), J2.A9 (VBUS2), J2.B4 (VBUS3), J2.B9 (VBUS4), R14.2, U1.4 (IN), U1.6 (IN), U4.1 (EN), U4.4 (VIN)
ADC_ChanA: J4.21, J5.14
ADC_ChanB: J4.22, J5.15
Clock24MHz: U3.33 (XTALIN/CLKIN), U6.33 (XTAL1(CLKIN)), X1.3 (OUT)
D1+: J2.A6 (D1+), J2.B6 (D2+), U3.31 (USBDP_UP)
D1-: J2.A7 (D1-), J2.B7 (D2-), U3.30 (USBDM_UP)
DAC_ChanA: J4.27, J5.17
DAC_ChanB: J4.29, J5.18
ESP32Drive: U2.9 (3B), U3.18 (PRTPWR3/BC_EN3)
EnFPGA: R4.2, U1.3 (EN), U2.11 (4Y)
EspD+: U3.7 (USBDP_DN3/PRT_DIS_P3), U5.27 (IO19)
EspD-: U3.6 (USBDM_DN3/PRT_DIS_M3), U5.26 (IO18)
EspEnable: C19.1, R5.2, SW2.1, U2.10 (3Y), U5.8 (EN)
EspIO3: J1.30, U5.6 (IO3)
EspIO4: J1.26, U5.18 (IO4)
EspIO5: J1.24, U5.19 (IO5)
EspIO6: J1.22, U5.20 (IO6)
EspIO7: J1.20, U5.21 (IO7)
EspIO10: J1.28, U5.16 (IO10)
EspRxd: J1.18, U5.30 (RXD0)
EspTxd: J1.16, U5.31 (TXD0)
FPGADrive: U2.12 (4A), U3.12 (PRTPWR1/BC_EN1)
GND: C1.2, C2.2, C3.2, C4.2, C5.2, C6.2, C7.2, C8.2, C9.2, C11.2, C12.2, C13.2, C14.2, C15.1, C16.2, C17.2, C18.2, C19.2, C20.1, C21.2, C22.2, C23.2, C24.2, C25.2, C26.2, D1.3, J1.40, J1.G1 (GND), J1.G2 (GND), J1.G3 (GND), J1.G4 (GND), J2.A1 (GND1), J2.A12 (GND2), J2.B1 (GND3), J2.B12 (GND4), J2.S1 (SHIELD), J2.S2 (SHIELD), J2.S3 (SHIELD), J2.S4 (SHIELD), J3.6 (VSS), J3.G1 (SHIELD_GND), J3.G2 (SHIELD_GND__1), J3.G3 (SHIELD_GND__2), J4.19, J4.20, J4.24, J4.25, J4.26, J4.28, J4.30, J5.9, J5.10, J5.16, J5.27, J5.28, R1.1, R2.1, R8.2, R9.1, R10.1, R11.1, R12.1, R13.1, R15.1, R20.2, R21.2, R24.2, SW1.2, SW2.2, SW3.2, U1.2 (GND), U1.5 (GND), U2.6 (2B), U2.7 (GND), U3.11 (TEST), U3.37 (EPAD), U4.2 (GND), U5.1 (GND), U5.2 (GND), U5.11 (GND), U5.14 (GND), U5.36 (GND), U5.37 (GND), U5.38 (GND), U5.39 (GND), U5.40 (GND), U5.41 (GND), U5.42 (GND), U5.43 (GND), U5.44 (GND), U5.45 (GND), U5.46 (GND), U5.47 (GND), U5.48 (GND), U5.49 (GND), U5.50 (GND), U5.51 (GND), U5.52 (GND), U5.53 (GND), U5.54 (GND), U5.55 (GND), U5.56 (GND), U5.57 (GND), U5.58 (GND), U5.59 (GND), U5.60 (GND), U5.61 (GND), U6.28 (TEST), U6.30 (SD_WP), U6.37 (EPAD), U7.1, U7.9, U7.10, X1.2 (GND)
unnamed: D1.1, R22.2
unnamed: D1.4, R23.2
unnamed: J1.01, J1.39
unnamed: J2.A5 (CC1), R1.2
unnamed: J2.B5 (CC2), R2.2
unnamed: J1.32, J1.34, U1.1 (OUT)
unnamed: C3.1, U3.14 (CRFILT)
unnamed: R10.2, U3.25 (HS_IND/CFG_SEL1)
unnamed: R6.1, U3.13 (OCS_N1), U3.17 (OCS_N2), U3.19 (OCS_N3)
unnamed: C12.1, U3.34 (PLLFILT)
unnamed: R13.2, U3.35 (RBIAS)
unnamed: C14.1, R16.1, SW1.1, U3.26 (RESET_N)
unnamed: R11.2, U3.24 (SCL/SMBCLK/CFG_SEL0)
unnamed: R12.2, U3.22 (SDA/SMBDATA/NON_REM1)
unnamed: R9.2, U3.28 (SUSP_IND/LOCAL_PWR/NON_REM0)
unnamed: R14.1, R15.2, U3.27 (VBUS_DET)
unnamed: C10.2, R7.2, R8.1, U4.5 (FB)
unnamed: L1.1, U4.3 (SW)
unnamed: C17.1, U5.12 (IO0), Y1.1
unnamed: C16.1, U5.13 (IO1), Y1.2
unnamed: R17.1, U5.5 (IO2)
unnamed: R18.1, U5.22 (IO8)
unnamed: SW3.1, U5.23 (IO9)
unnamed: R23.1, U6.1 (LED)
unnamed: R21.1, U6.35 (RBIAS)
unnamed: R20.1, U6.31 (TXD/SCK)
unnamed: C25.1, U6.13 (VDD18)
unnamed: C21.1, U6.34 (VDD18PLL)
PMOD1_1: J1.23, J4.10, J5.19
PMOD1_2: J1.27, J4.12, J5.21
PMOD1_3: J1.31, J4.14, J5.23
PMOD1_4: J1.35, J4.16, J5.25
PMOD1_7: J1.25, J4.9, J5.20
PMOD1_8: J1.29, J4.11, J5.22
PMOD1_9: J1.33, J4.13, J5.24
PMOD1_10: J1.37, J4.15, J5.26
PMOD2_1: J1.07, J4.2, J5.1
PMOD2_2: J1.11, J4.4, J5.3
PMOD2_3: J1.15, J4.6, J5.5
PMOD2_4: J1.19, J4.8, J5.7
PMOD2_7: J1.09, J4.1, J5.2
PMOD2_8: J1.13, J4.3, J5.4
PMOD2_9: J1.17, J4.5, J5.6
PMOD2_10: J1.21, J4.7, J5.8
SDCReset: J1.14, R24.1, U2.5 (2A)
SDCnReset: D1.2, R3.1, U2.3 (1Y), U2.4 (2Y), U6.18 (RESET_N), U7.19
SDCnResetDrive: U2.1 (1A), U3.16 (PRTPWR2/BC_EN2)
SdClk: J3.5 (CLK), U6.9 (SD_CLK), U7.6
SdClkB: J1.12, U7.14
SdCmd: J3.3 (CMD), U6.11 (SD_CMD), U7.5
SdCmdB: J1.10, U7.15
SdD0: J3.7 (DAT0), U6.5 (SD_D0), U7.7
SdD0B: J1.03, U7.13
SdD1: J3.8 (DAT1), U6.4 (SD_D1), U7.8
SdD1B: J1.05, U7.12
SdD2: J3.1 (DAT2), U6.25 (SD_D2), U7.3
SdD2B: J1.06, U7.17
SdD3: J3.2 (CD/DAT3), U6.23 (SD_D3), U7.4
SdD3B: J1.08, U7.16
SdcD+: U3.4 (USBDP_DN2/PRT_DIS_P2), U6.2 (USB+)
SdcD-: U3.3 (USBDM_DN2/PRT_DIS_M2), U6.3 (USB-)
SdnDet: J3.CD_PIN, R19.1, U6.26 (SD_NCD), U7.2
SdnDetB: J1.04, U7.18
UsbD+: J1.38, U3.2 (USBDP_DN1/PRT_DIS_P1)
UsbD-: J1.36, U3.1 (USBDM_DN1/PRT_DIS_M1)
VREF: J4.23, J5.13

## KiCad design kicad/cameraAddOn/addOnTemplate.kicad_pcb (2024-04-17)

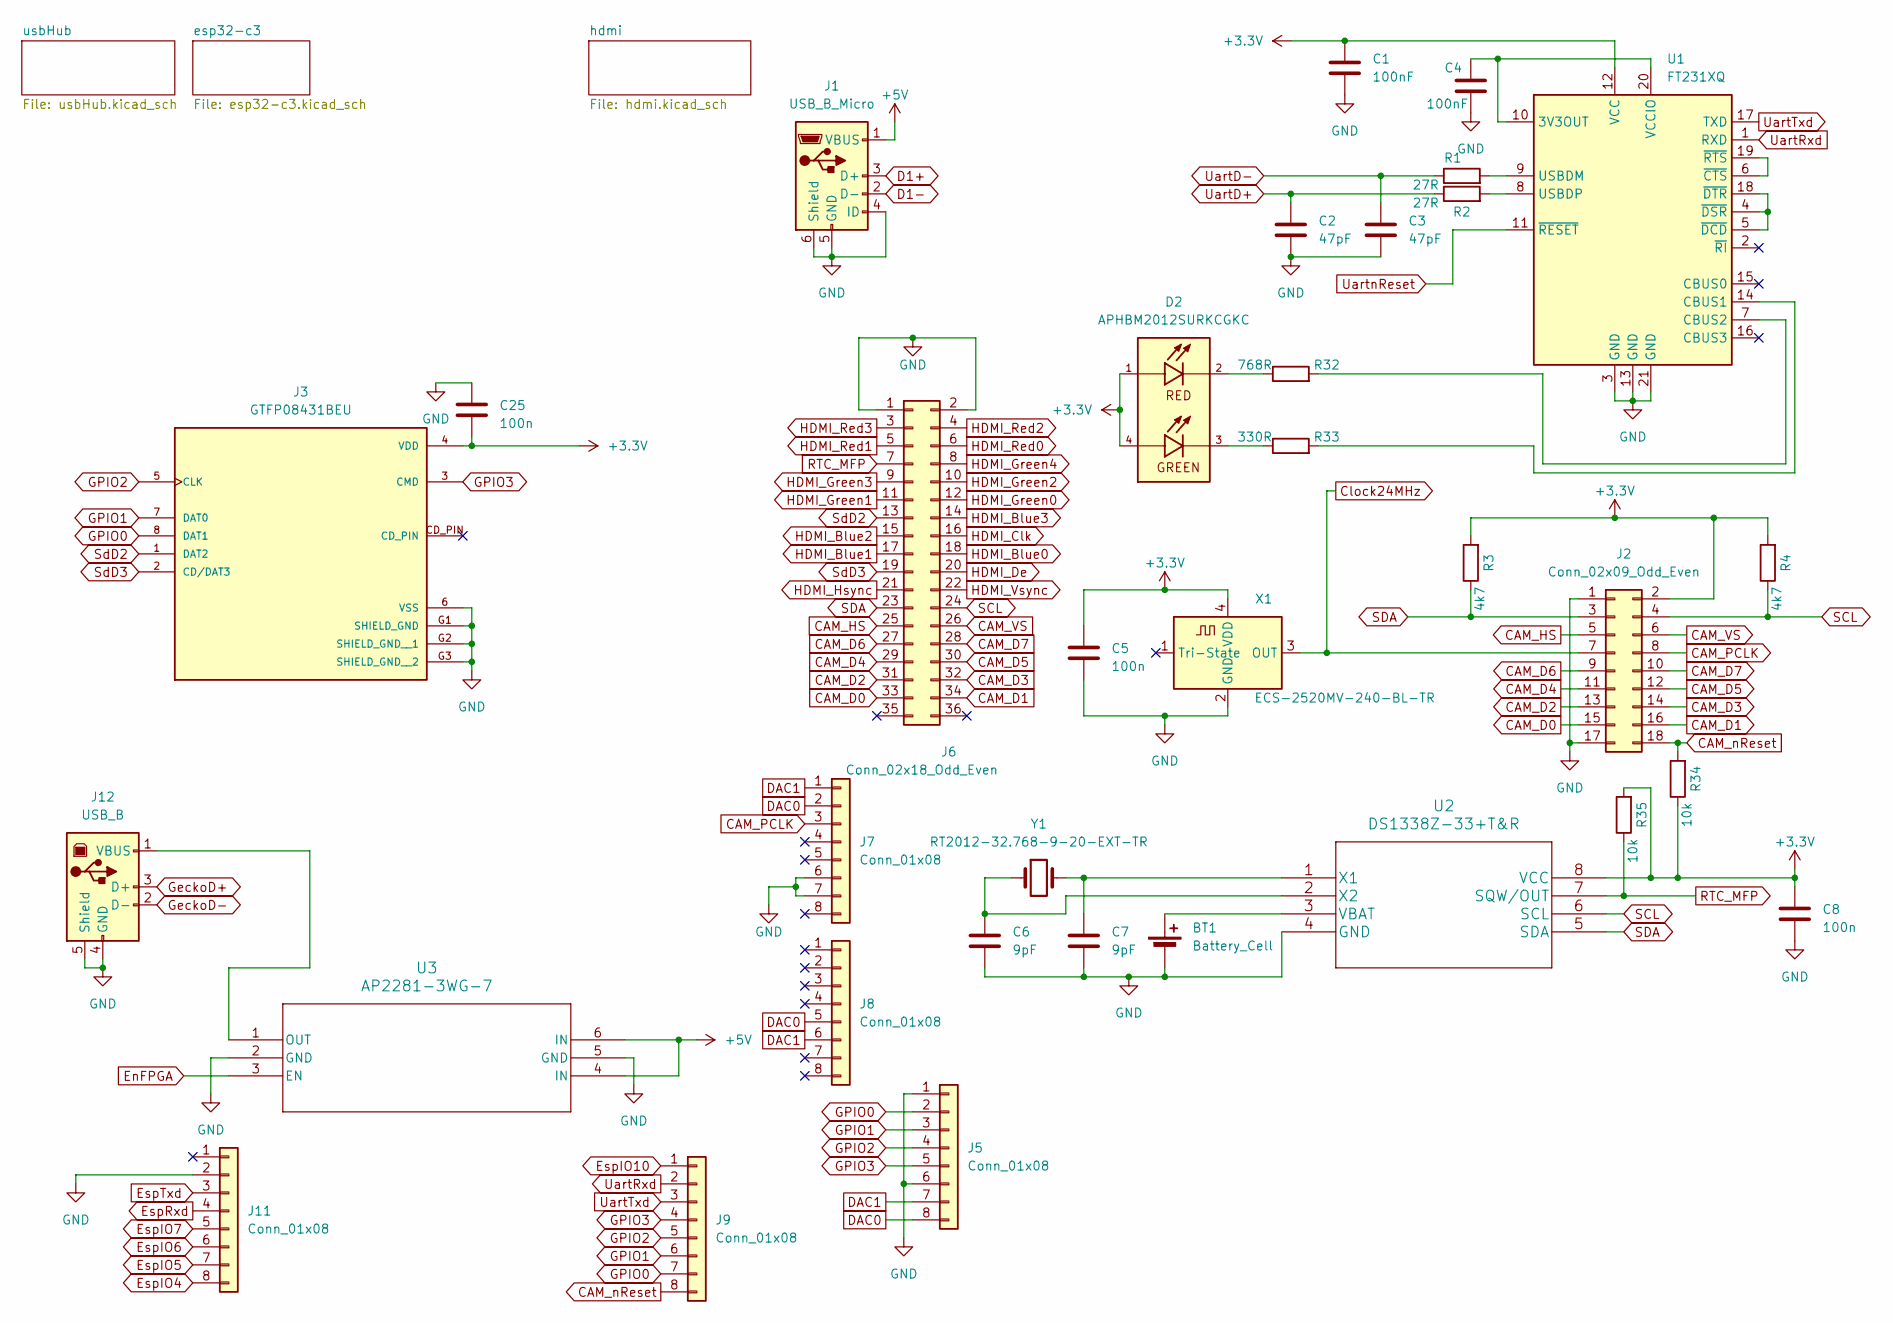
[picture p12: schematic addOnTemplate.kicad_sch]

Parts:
BT1: Battery_Cell; BatteryHolder_Keystone_1060_1x2032
C1, C4: 100nF; C_0402_1005Metric
C2, C3: 47pF; C_0402_1005Metric
C5, C8, C25: 100n; C_0402_1005Metric
C6, C7: 9pF; C_0402_1005Metric
D2: APHBM2012SURKCGKC; LED_APHBM2012SURKCGKC
J1: USB_B_Micro; USB_Micro-AB_Molex_47590-0001
J2: Conn_02x09_Odd_Even; PinSocket_2x09_P2.54mm_Horizontal
J3: GTFP08431BEU; AMPHENOL_GTFP08431BEU; PARTREV F
J5: Conn_01x08; PinHeader_2x04_P2.54mm_Horizontal
J6: Conn_02x18_Odd_Even; PinHeader_2x18_P2.54mm_Vertical
J7, J8, J9, J11: Conn_01x08; PinHeader_1x08_P2.54mm_Vertical
J12: USB_B; USB_A_Molex_67643_Horizontal
R1, R2: 27R; R_0402_1005Metric
R3, R4: 4k7; R_0402_1005Metric
R32: 768R; R_0402_1005Metric
R33: 330R; R_0402_1005Metric
R34, R35: 10k; R_0402_1005Metric
U1: FT231XQ; QFN-20-1EP_4x4mm_P0.5mm_EP2.5x2.5mm
U2: DS1338Z-33+T&R; DS1338Z-33&plus_T&R
U3: AP2281-3WG-7; SOT26_DIO
X1: ECS-2520MV-240-BL-TR; Oscillator_SMD_ECS_2520MV-xxx-xx-4Pin_2.5x2.0mm
Y1: RT2012-32.768-9-20-EXT-TR; Crystal_SMD_2012-2Pin_2.0x1.2mm

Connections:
+3.3V: C1.1, C5.1, C8.1, C25.2, D2.1, D2.4, J2.2, J3.4 (VDD), R3.2, R4.2, R34.1, R35.2, U1.12 (VCC), U2.8 (VCC), X1.4 (VDD); also elsewhere on the board
+5V: J1.1 (VBUS), U3.4 (IN), U3.6 (IN); also elsewhere on the board
CAM_D0: J2.15, J6.33
CAM_D1: J2.16, J6.34
CAM_D2: J2.13, J6.31
CAM_D3: J2.14, J6.32
CAM_D4: J2.11, J6.29
CAM_D5: J2.12, J6.30
CAM_D6: J2.9, J6.27
CAM_D7: J2.10, J6.28
CAM_HS: J2.5, J6.25
CAM_PCLK: J2.8, J7.3
CAM_VS: J2.6, J6.26
CAM_nReset: J2.18, J9.8, R34.2
Clock24MHz: J2.7, X1.3 (OUT); also elsewhere on the board
D1+: J1.3 (D+); also elsewhere on the board
D1-: J1.2 (D-); also elsewhere on the board
DAC0: J5.8, J7.2, J8.5
DAC1: J5.7, J7.1, J8.6
EnFPGA: U3.3 (EN); also elsewhere on the board
EspIO4: J11.8; also elsewhere on the board
EspIO5: J11.7; also elsewhere on the board
EspIO6: J11.6; also elsewhere on the board
EspIO7: J11.5; also elsewhere on the board
EspIO10: J9.1; also elsewhere on the board
EspRxd: J11.4; also elsewhere on the board
EspTxd: J11.3; also elsewhere on the board
GND: BT1.2 (-), C1.2, C2.2, C3.2, C4.2, C5.2, C6.2, C7.2, C8.2, C25.1, J1.4 (ID), J1.5 (GND), J1.6 (Shield), J2.1, J2.17, J3.6 (VSS), J3.G1 (SHIELD_GND), J3.G2 (SHIELD_GND__1), J3.G3 (SHIELD_GND__2), J5.1, J5.6, J6.1, J6.2, J7.6, J7.7, J11.2, J12.4 (GND), J12.5 (Shield), U1.3 (GND), U1.13 (GND), U1.21 (GND), U2.4 (GND), U3.2 (GND), U3.5 (GND), X1.2 (GND); also elsewhere on the board
GPIO0: J3.8 (DAT1), J5.2, J9.7
GPIO1: J3.7 (DAT0), J5.3, J9.6
GPIO2: J3.5 (CLK), J5.4, J9.5
GPIO3: J3.3 (CMD), J5.5, J9.4
GeckoD+: J12.3 (D+); also elsewhere on the board
GeckoD-: J12.2 (D-); also elsewhere on the board
HDMI_Blue0: J6.18; also elsewhere on the board
HDMI_Blue1: J6.17; also elsewhere on the board
HDMI_Blue2: J6.15; also elsewhere on the board
HDMI_Blue3: J6.14; also elsewhere on the board
HDMI_Clk: J6.16; also elsewhere on the board
HDMI_De: J6.20; also elsewhere on the board
HDMI_Green0: J6.12; also elsewhere on the board
HDMI_Green1: J6.11; also elsewhere on the board
HDMI_Green2: J6.10; also elsewhere on the board
HDMI_Green3: J6.9; also elsewhere on the board
HDMI_Green4: J6.8; also elsewhere on the board
HDMI_Hsync: J6.21; also elsewhere on the board
HDMI_Red0: J6.6; also elsewhere on the board
HDMI_Red1: J6.5; also elsewhere on the board
HDMI_Red2: J6.4; also elsewhere on the board
HDMI_Red3: J6.3; also elsewhere on the board
HDMI_Vsync: J6.22; also elsewhere on the board
unnamed: BT1.1 (+), U2.3 (VBAT)
unnamed: D2.2, R32.1
unnamed: D2.3, R33.1
unnamed: J12.1 (VBUS), U3.1 (OUT)
unnamed: C4.1, U1.10 (3V3OUT), U1.20 (VCCIO)
unnamed: R33.2, U1.14 (CBUS1)
unnamed: R32.2, U1.7 (CBUS2)
unnamed: R1.2, U1.9 (USBDM)
unnamed: R2.2, U1.8 (USBDP)
unnamed: U1.6 (~CTS), U1.19 (~RTS)
unnamed: U1.4 (~DSR), U1.5 (~DCD), U1.18 (~DTR)
unnamed: C7.1, U2.1 (X1), Y1.2
unnamed: C6.1, U2.2 (X2), Y1.1
RTC_MFP: J6.7, R35.1, U2.7 (SQW/OUT)
SCL: J2.4, J6.24, R4.1, U2.6 (SCL)
SDA: J2.3, J6.23, R3.1, U2.5 (SDA)
SdD2: J3.1 (DAT2), J6.13
SdD3: J3.2 (CD/DAT3), J6.19
UartD+: C2.1, R2.1; also elsewhere on the board
UartD-: C3.1, R1.1; also elsewhere on the board
UartRxd: J9.2, U1.1 (RXD)
UartTxd: J9.3, U1.17 (TXD)
UartnReset: U1.11 (~RESET); also elsewhere on the board

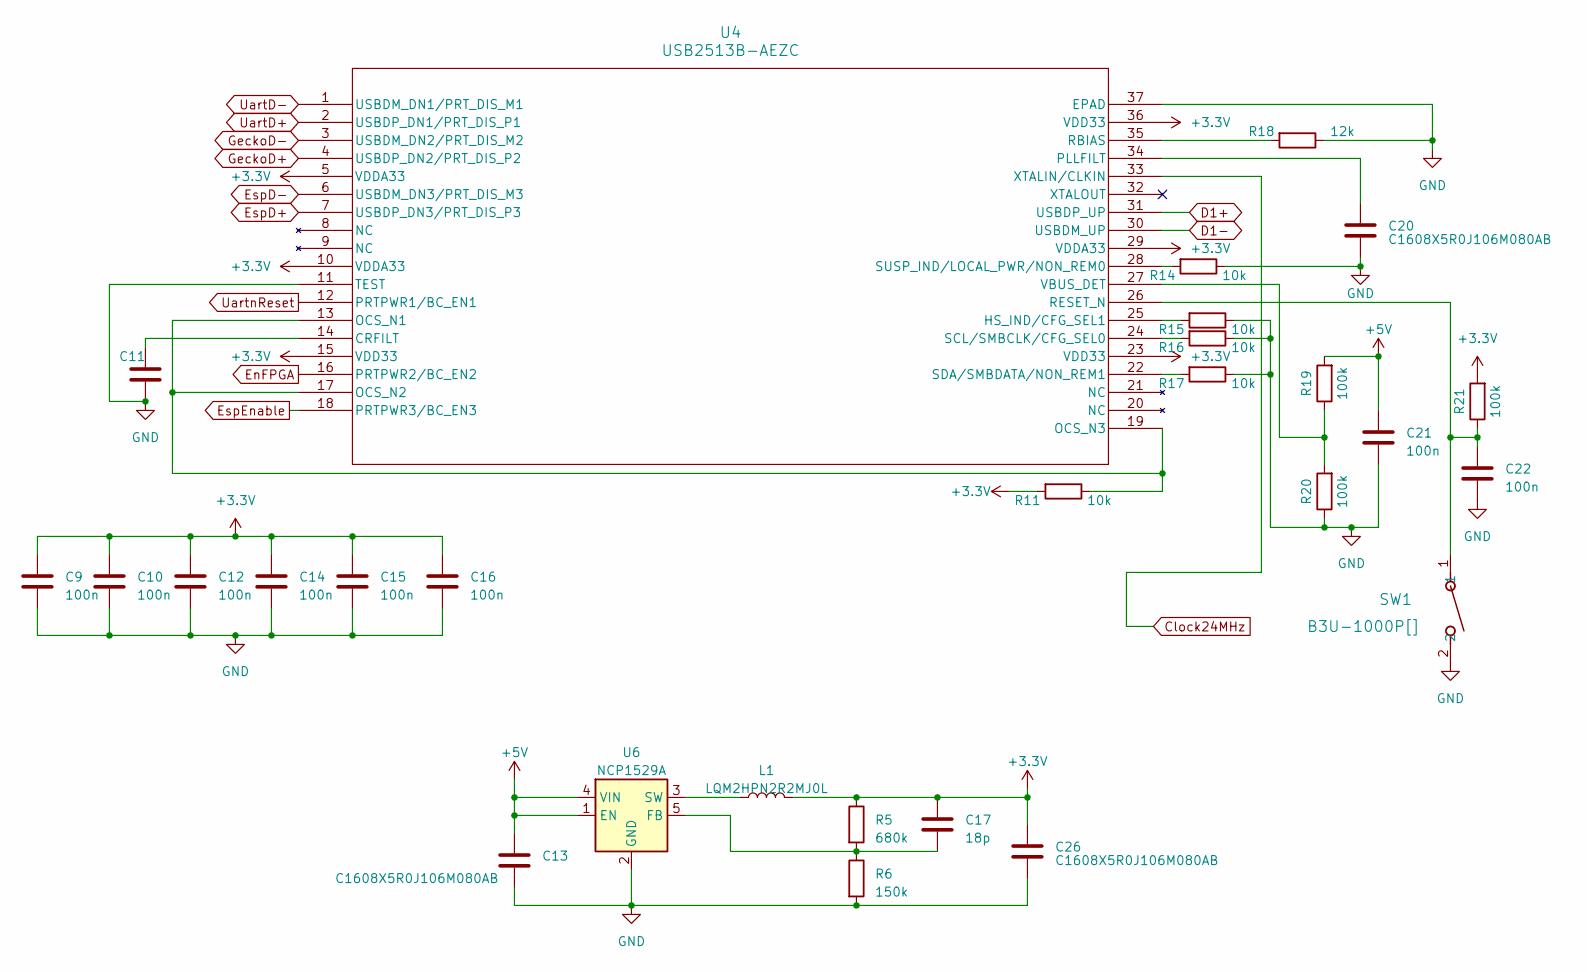
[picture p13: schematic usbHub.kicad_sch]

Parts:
C9, C10, C12, C14, C15, C16, C21, C22: 100n; C_0402_1005Metric
C11, C13, C20, C26: C1608X5R0J106M080AB; C_0603_1608Metric
C17: 18p; C_0402_1005Metric
L1: LQM2HPN2R2MJ0L
R5: 680k; R_0402_1005Metric
R6: 150k; R_0402_1005Metric
R11, R14, R15, R16, R17: 10k; R_0402_1005Metric
R18: 12k; R_0402_1005Metric
R19, R20, R21: 100k; R_0402_1005Metric
SW1: B3U-1000P[]; SW_B3U-1000P_OMR
U4: USB2513B-AEZC; QFN36_6X6MC_MCH
U6: NCP1529A; SOT-23-5

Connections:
+3.3V: C9.1, C10.1, C12.1, C14.1, C15.1, C16.1, C17.1, C26.1, L1.2, R5.1, R11.2, R21.2, U4.5 (VDDA33), U4.10 (VDDA33), U4.15 (VDD33), U4.23 (VDD33), U4.29 (VDDA33), U4.36 (VDD33); also elsewhere on the board
+5V: C13.1, C21.1, R19.2, U6.1 (EN), U6.4 (VIN); also elsewhere on the board
Clock24MHz: U4.33 (XTALIN/CLKIN); also elsewhere on the board
D1+: U4.31 (USBDP_UP); also elsewhere on the board
D1-: U4.30 (USBDM_UP); also elsewhere on the board
EnFPGA: U4.16 (PRTPWR2/BC_EN2); also elsewhere on the board
EspD+: U4.7 (USBDP_DN3/PRT_DIS_P3); also elsewhere on the board
EspD-: U4.6 (USBDM_DN3/PRT_DIS_M3); also elsewhere on the board
EspEnable: U4.18 (PRTPWR3/BC_EN3); also elsewhere on the board
GND: C9.2, C10.2, C11.2, C12.2, C13.2, C14.2, C15.2, C16.2, C20.2, C21.2, C22.2, C26.2, R6.2, R14.1, R15.1, R16.1, R17.1, R18.1, R20.1, SW1.2, U4.11 (TEST), U4.37 (EPAD), U6.2 (GND); also elsewhere on the board
GeckoD+: U4.4 (USBDP_DN2/PRT_DIS_P2); also elsewhere on the board
GeckoD-: U4.3 (USBDM_DN2/PRT_DIS_M2); also elsewhere on the board
unnamed: C11.1, U4.14 (CRFILT)
unnamed: R15.2, U4.25 (HS_IND/CFG_SEL1)
unnamed: R11.1, U4.13 (OCS_N1), U4.17 (OCS_N2), U4.19 (OCS_N3)
unnamed: C20.1, U4.34 (PLLFILT)
unnamed: R18.2, U4.35 (RBIAS)
unnamed: C22.1, R21.1, SW1.1, U4.26 (RESET_N)
unnamed: R16.2, U4.24 (SCL/SMBCLK/CFG_SEL0)
unnamed: R17.2, U4.22 (SDA/SMBDATA/NON_REM1)
unnamed: R14.2, U4.28 (SUSP_IND/LOCAL_PWR/NON_REM0)
unnamed: R19.1, R20.2, U4.27 (VBUS_DET)
unnamed: C17.2, R5.2, R6.1, U6.5 (FB)
unnamed: L1.1, U6.3 (SW)
UartD+: U4.2 (USBDP_DN1/PRT_DIS_P1); also elsewhere on the board
UartD-: U4.1 (USBDM_DN1/PRT_DIS_M1); also elsewhere on the board
UartnReset: U4.12 (PRTPWR1/BC_EN1); also elsewhere on the board

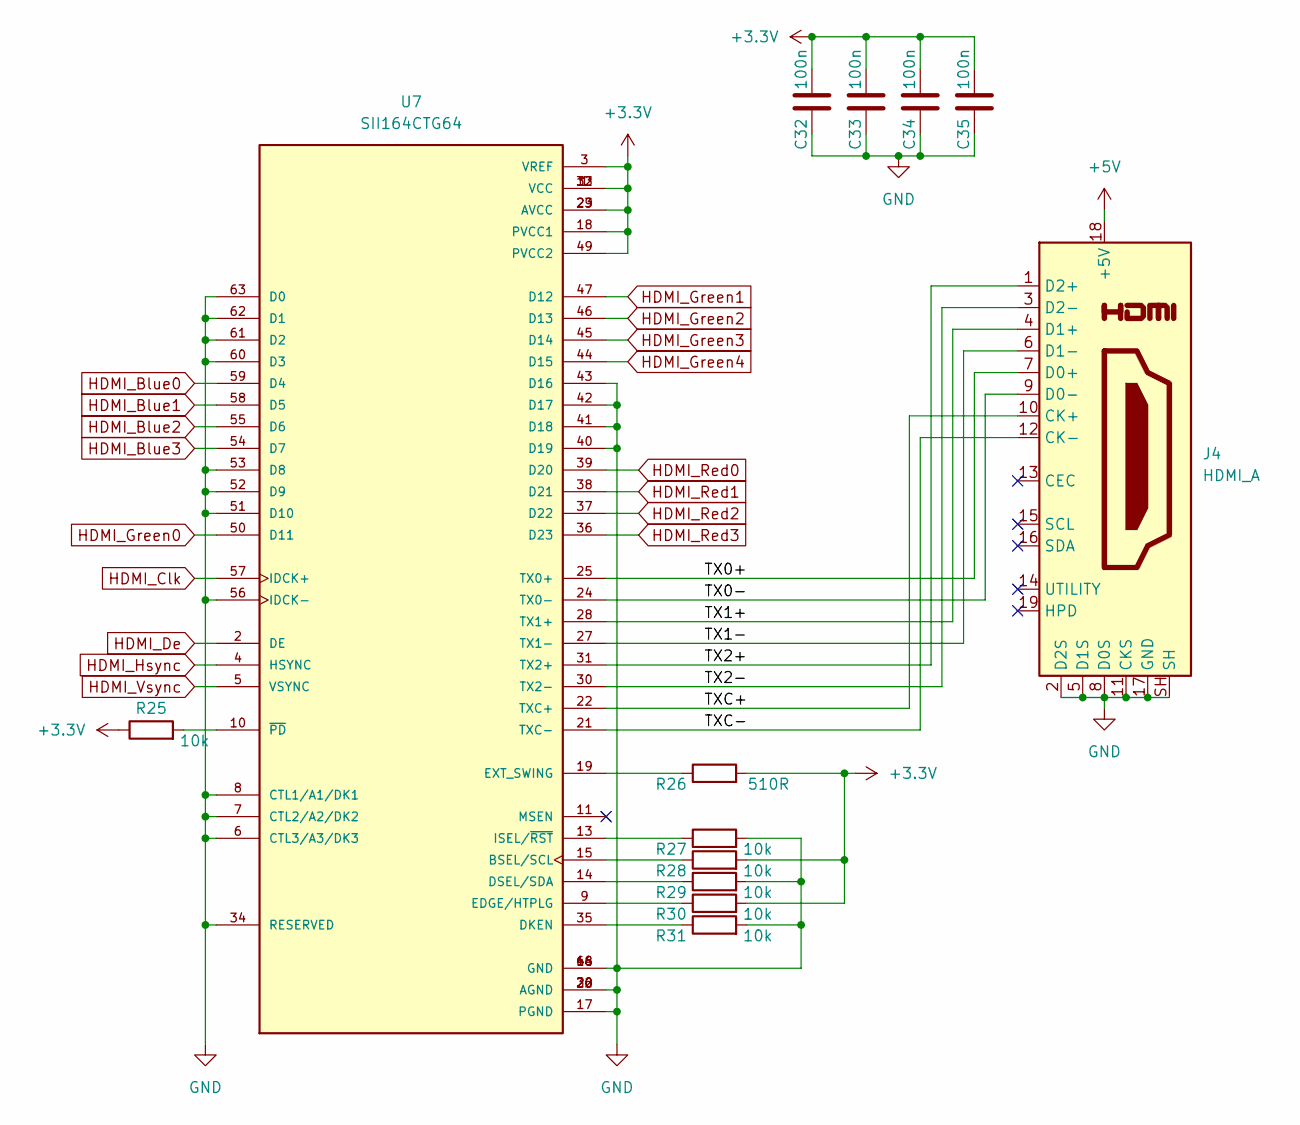
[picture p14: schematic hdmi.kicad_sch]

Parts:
C32, C33, C34, C35: 100n; R_0402_1005Metric
J4: HDMI_A; HDMI_A_Molex_208658-1001_Horizontal
R25, R27, R28, R29, R30, R31: 10k; R_0402_1005Metric
R26: 510R; R_0402_1005Metric
U7: SII164CTG64; QFP50P1200X1200X120-64N; PARTREV E; DigiKey_Part_Number 220-2189-ND

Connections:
+3.3V: C32.2, C33.2, C34.2, C35.2, R25.1, R26.2, R28.2, R30.2, U7.1 (VCC), U7.3 (VREF), U7.12 (VCC), U7.18 (PVCC1), U7.23 (AVCC), U7.29 (AVCC), U7.33 (VCC), U7.49 (PVCC2); also elsewhere on the board
+5V: J4.18 (+5V); also elsewhere on the board
/hdmi/TX0+: J4.7 (D0+), U7.25 (TX0+)
/hdmi/TX0-: J4.9 (D0-), U7.24 (TX0-)
/hdmi/TX1+: J4.4 (D1+), U7.28 (TX1+)
/hdmi/TX1-: J4.6 (D1-), U7.27 (TX1-)
/hdmi/TX2+: J4.1 (D2+), U7.31 (TX2+)
/hdmi/TX2-: J4.3 (D2-), U7.30 (TX2-)
/hdmi/TXC+: J4.10 (CK+), U7.22 (TXC+)
/hdmi/TXC-: J4.12 (CK-), U7.21 (TXC-)
GND: C32.1, C33.1, C34.1, C35.1, J4.2 (D2S), J4.5 (D1S), J4.8 (D0S), J4.11 (CKS), J4.17 (GND), J4.SH, R27.2, R29.2, R31.2, U7.6 (CTL3/A3/DK3), U7.7 (CTL2/A2/DK2), U7.8 (CTL1/A1/DK1), U7.16 (GND), U7.17 (PGND), U7.20 (AGND), U7.26 (AGND), U7.32 (AGND), U7.34 (RESERVED), U7.40 (D19), U7.41 (D18), U7.42 (D17), U7.43 (D16), U7.48 (GND), U7.51 (D10), U7.52 (D9), U7.53 (D8), U7.56 (IDCK-), U7.60 (D3), U7.61 (D2), U7.62 (D1), U7.63 (D0), U7.64 (GND); also elsewhere on the board
HDMI_Blue0: U7.59 (D4); also elsewhere on the board
HDMI_Blue1: U7.58 (D5); also elsewhere on the board
HDMI_Blue2: U7.55 (D6); also elsewhere on the board
HDMI_Blue3: U7.54 (D7); also elsewhere on the board
HDMI_Clk: U7.57 (IDCK+); also elsewhere on the board
HDMI_De: U7.2 (DE); also elsewhere on the board
HDMI_Green0: U7.50 (D11); also elsewhere on the board
HDMI_Green1: U7.47 (D12); also elsewhere on the board
HDMI_Green2: U7.46 (D13); also elsewhere on the board
HDMI_Green3: U7.45 (D14); also elsewhere on the board
HDMI_Green4: U7.44 (D15); also elsewhere on the board
HDMI_Hsync: U7.4 (HSYNC); also elsewhere on the board
HDMI_Red0: U7.39 (D20); also elsewhere on the board
HDMI_Red1: U7.38 (D21); also elsewhere on the board
HDMI_Red2: U7.37 (D22); also elsewhere on the board
HDMI_Red3: U7.36 (D23); also elsewhere on the board
HDMI_Vsync: U7.5 (VSYNC); also elsewhere on the board
unnamed: R28.1, U7.15 (BSEL/SCL)
unnamed: R31.1, U7.35 (DKEN)
unnamed: R29.1, U7.14 (DSEL/SDA)
unnamed: R30.1, U7.9 (EDGE/HTPLG)
unnamed: R26.1, U7.19 (EXT_SWING)
unnamed: R27.1, U7.13 (ISEL/~RST)
unnamed: R25.2, U7.10 (~PD)

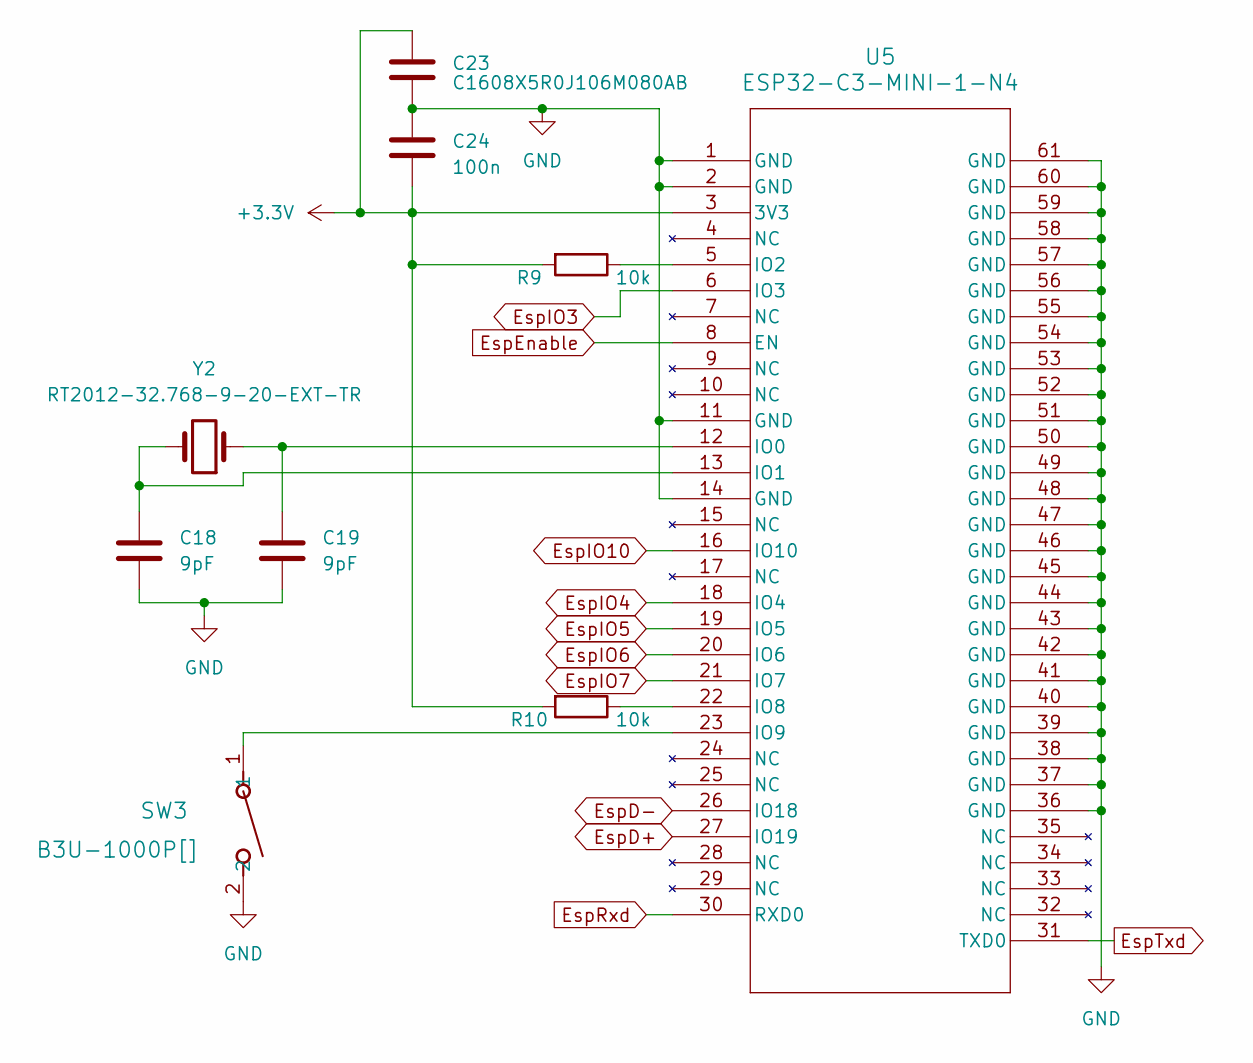
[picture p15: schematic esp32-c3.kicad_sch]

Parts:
C18, C19: 9pF; C_0402_1005Metric
C23: C1608X5R0J106M080AB; C_0603_1608Metric
C24: 100n; C_0402_1005Metric
R9, R10: 10k; R_0402_1005Metric
SW3: B3U-1000P[]; SW_B3U-1000P_OMR
U5: ESP32-C3-MINI-1-N4; ESP32-C3-MINI-1_EXP
Y2: RT2012-32.768-9-20-EXT-TR; Crystal_SMD_2012-2Pin_2.0x1.2mm

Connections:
+3.3V: C23.1, C24.2, R9.2, R10.2, U5.3 (3V3); also elsewhere on the board
EspD+: U5.27 (IO19); also elsewhere on the board
EspD-: U5.26 (IO18); also elsewhere on the board
EspEnable: U5.8 (EN); also elsewhere on the board
EspIO3: U5.6 (IO3)
EspIO4: U5.18 (IO4); also elsewhere on the board
EspIO5: U5.19 (IO5); also elsewhere on the board
EspIO6: U5.20 (IO6); also elsewhere on the board
EspIO7: U5.21 (IO7); also elsewhere on the board
EspIO10: U5.16 (IO10); also elsewhere on the board
EspRxd: U5.30 (RXD0); also elsewhere on the board
EspTxd: U5.31 (TXD0); also elsewhere on the board
GND: C18.2, C19.2, C23.2, C24.1, SW3.2, U5.1 (GND), U5.2 (GND), U5.11 (GND), U5.14 (GND), U5.36 (GND), U5.37 (GND), U5.38 (GND), U5.39 (GND), U5.40 (GND), U5.41 (GND), U5.42 (GND), U5.43 (GND), U5.44 (GND), U5.45 (GND), U5.46 (GND), U5.47 (GND), U5.48 (GND), U5.49 (GND), U5.50 (GND), U5.51 (GND), U5.52 (GND), U5.53 (GND), U5.54 (GND), U5.55 (GND), U5.56 (GND), U5.57 (GND), U5.58 (GND), U5.59 (GND), U5.60 (GND), U5.61 (GND); also elsewhere on the board
unnamed: C19.1, U5.12 (IO0), Y2.1
unnamed: C18.1, U5.13 (IO1), Y2.2
unnamed: R9.1, U5.5 (IO2)
unnamed: R10.1, U5.22 (IO8)
unnamed: SW3.1, U5.23 (IO9)

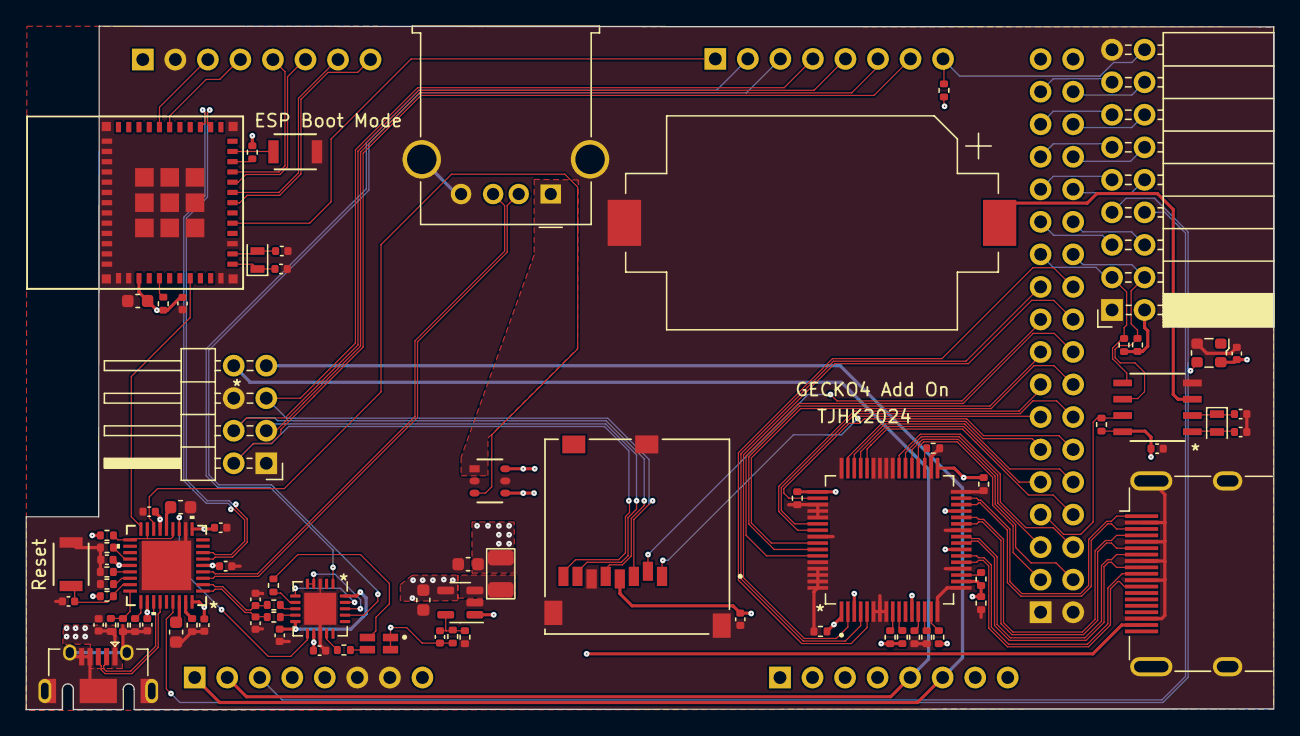
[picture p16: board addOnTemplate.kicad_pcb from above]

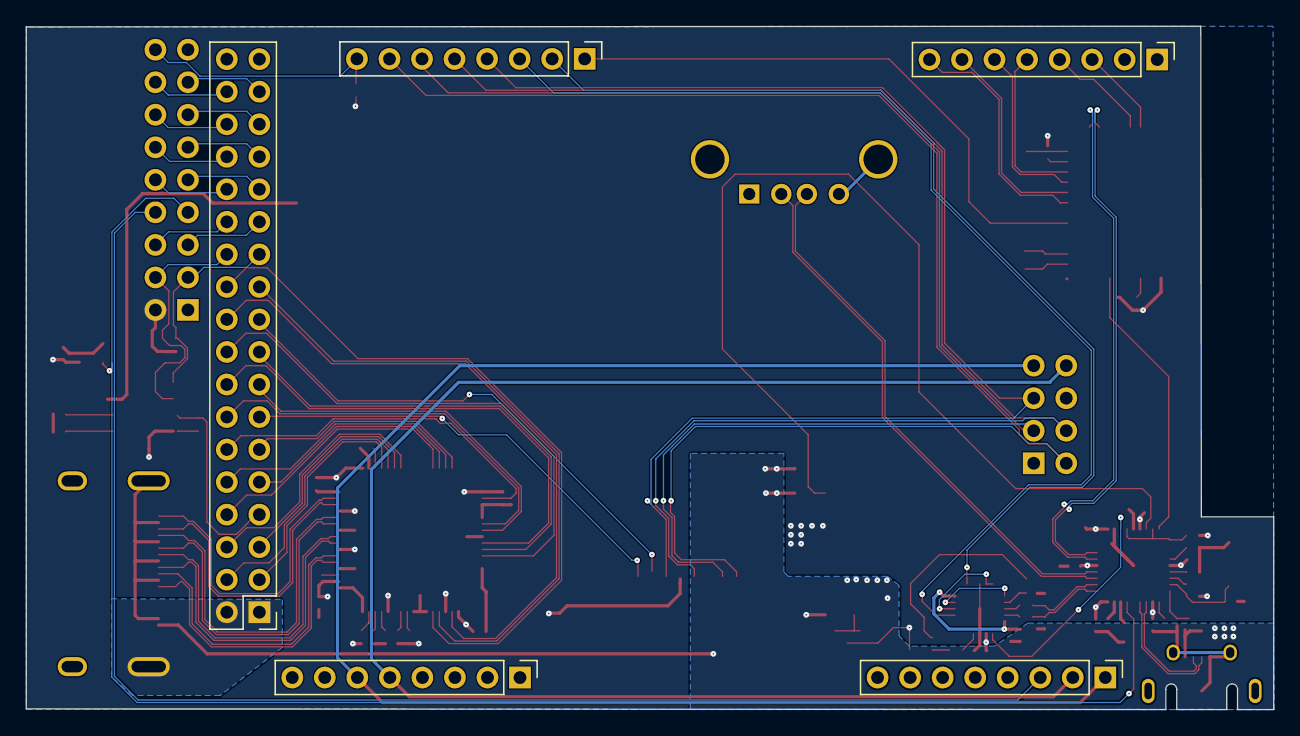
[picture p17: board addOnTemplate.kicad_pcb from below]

Board: 2 copper layers, 97.4 x 53.3 mm, 84 parts (5 on the bottom side), 109 nets.

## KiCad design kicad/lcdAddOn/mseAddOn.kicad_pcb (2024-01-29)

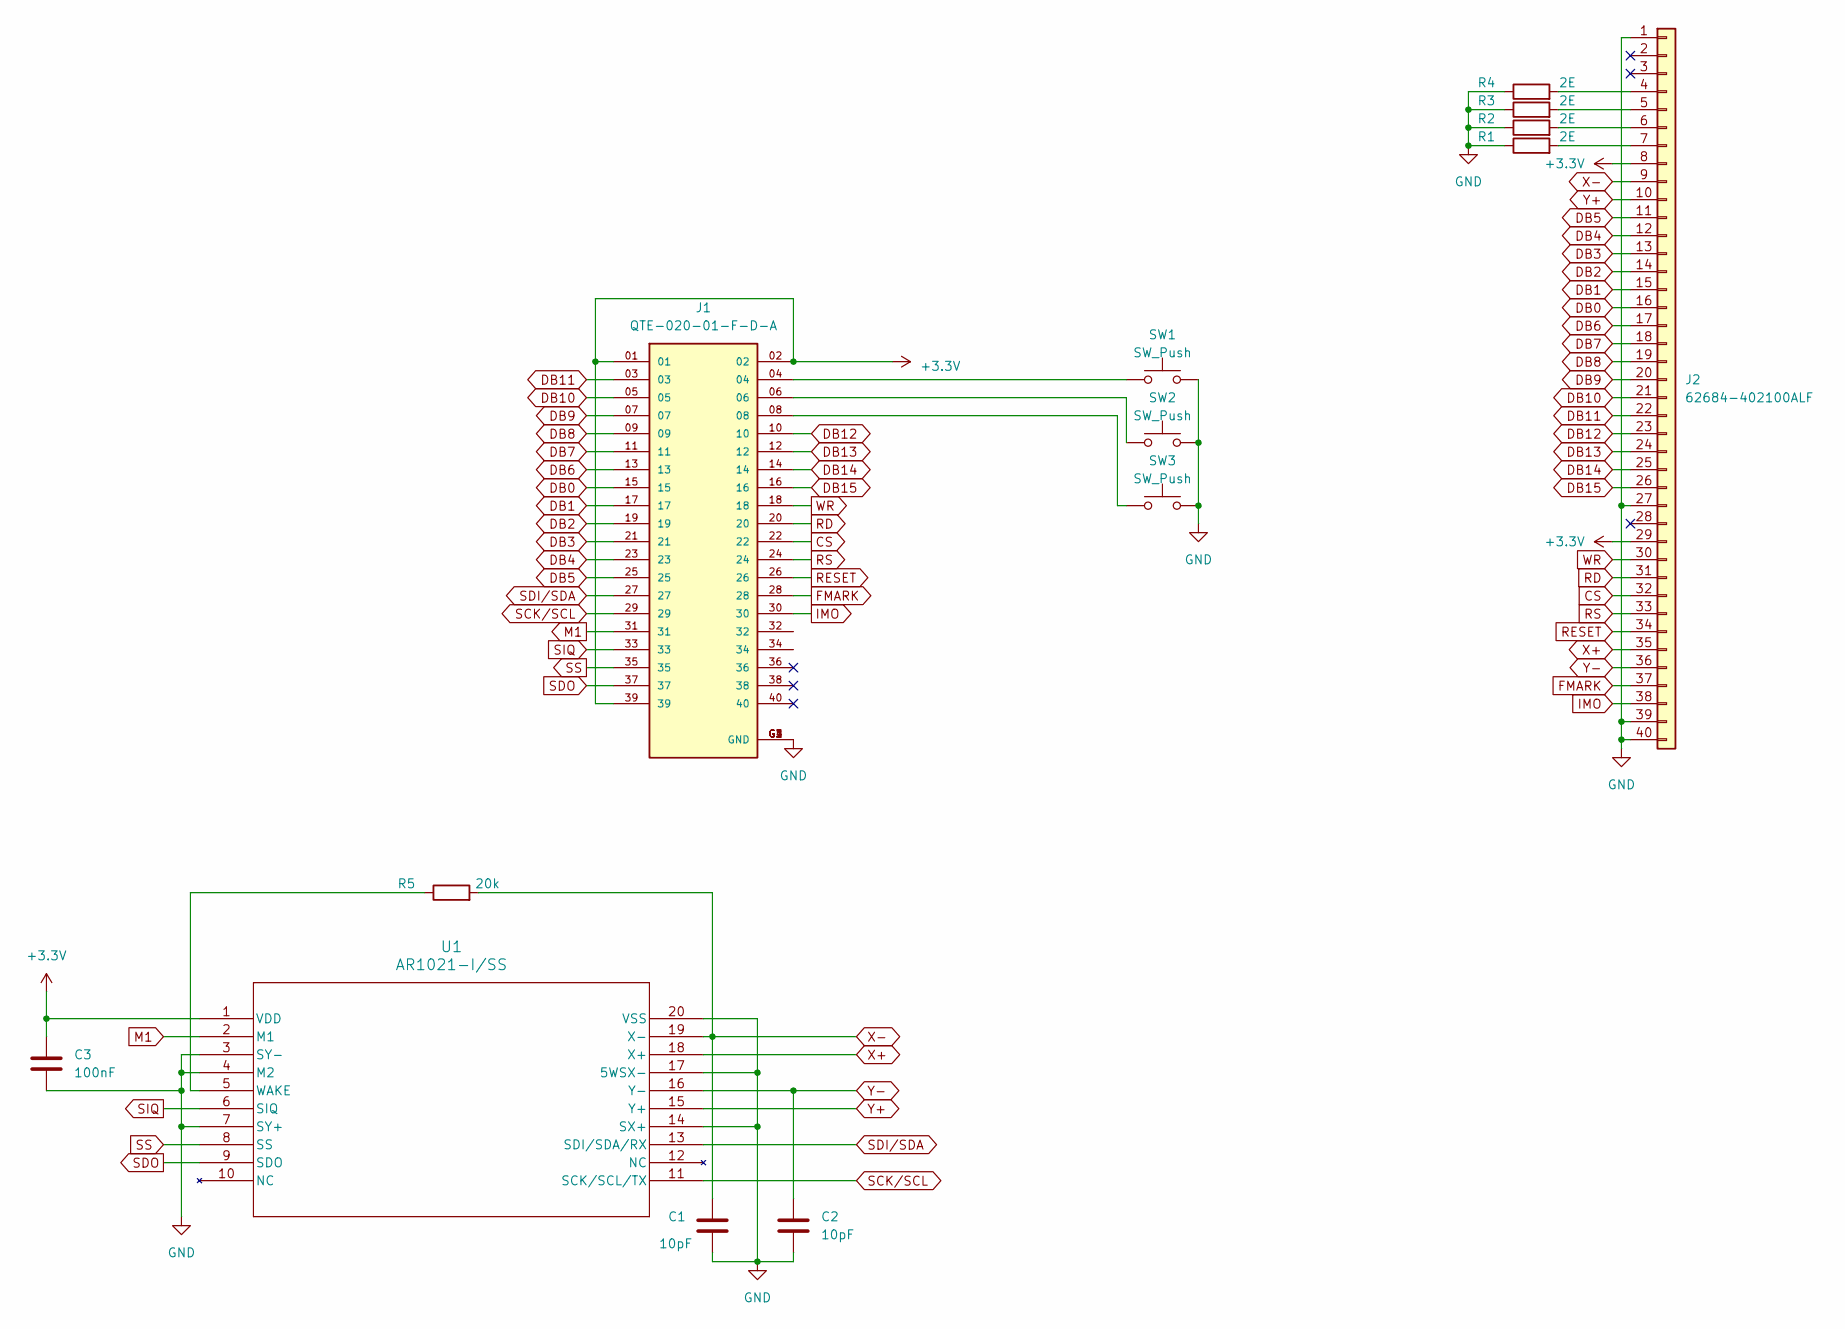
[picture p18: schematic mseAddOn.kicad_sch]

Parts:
C1, C2: 10pF; C_0402_1005Metric
C3: 100nF; C_0402_1005Metric
J1: QTE-020-01-F-D-A; SAMTEC_QTE-020-01-X-D-A; PARTREV K
J2: 62684-402100ALF; CONN_62684-402100ALF_AMP
R1, R2, R3, R4: 2E; R_0402_1005Metric
R5: 20k; R_0402_1005Metric
SW1, SW2, SW3: SW_Push; pushbutton
U1: AR1021-I/SS; SSOP20_MC_MCH

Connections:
+3.3V: C3.1, J1.01, J1.02, J1.39, J2.8, J2.29, U1.1 (VDD)
CS: J1.22, J2.32
DB0: J1.15, J2.16
DB1: J1.17, J2.15
DB2: J1.19, J2.14
DB3: J1.21, J2.13
DB4: J1.23, J2.12
DB5: J1.25, J2.11
DB6: J1.13, J2.17
DB7: J1.11, J2.18
DB8: J1.09, J2.19
DB9: J1.07, J2.20
DB10: J1.05, J2.21
DB11: J1.03, J2.22
DB12: J1.10, J2.23
DB13: J1.12, J2.24
DB14: J1.14, J2.25
DB15: J1.16, J2.26
FMARK: J1.28, J2.37
GND: C1.2, C2.2, C3.2, J1.G1 (GND), J1.G2 (GND), J1.G3 (GND), J1.G4 (GND), J2.1, J2.27, J2.39, J2.40, R1.1, R2.1, R3.1, R4.1, SW1.2, SW2.2, SW3.2, U1.3 (SY-), U1.4 (M2), U1.7 (SY+), U1.14 (SX+), U1.17 (5WSX-), U1.20 (VSS)
IMO: J1.30, J2.38
M1: J1.31, U1.2 (M1)
unnamed: J1.04, SW1.1
unnamed: J1.06, SW2.1
unnamed: J1.08, SW3.1
unnamed: J2.4, R4.2
unnamed: J2.5, R3.2
unnamed: J2.6, R2.2
unnamed: J2.7, R1.2
unnamed: R5.1, U1.5 (WAKE)
RD: J1.20, J2.31
RESET: J1.26, J2.34
RS: J1.24, J2.33
SCK/SCL: J1.29, U1.11 (SCK/SCL/TX)
SDI/SDA: J1.27, U1.13 (SDI/SDA/RX)
SDO: J1.37, U1.9 (SDO)
SIQ: J1.33, U1.6 (SIQ)
SS: J1.35, U1.8 (SS)
WR: J1.18, J2.30
X+: J2.35, U1.18 (X+)
X-: C1.1, J2.9, R5.2, U1.19 (X-)
Y+: J2.10, U1.15 (Y+)
Y-: C2.1, J2.36, U1.16 (Y-)

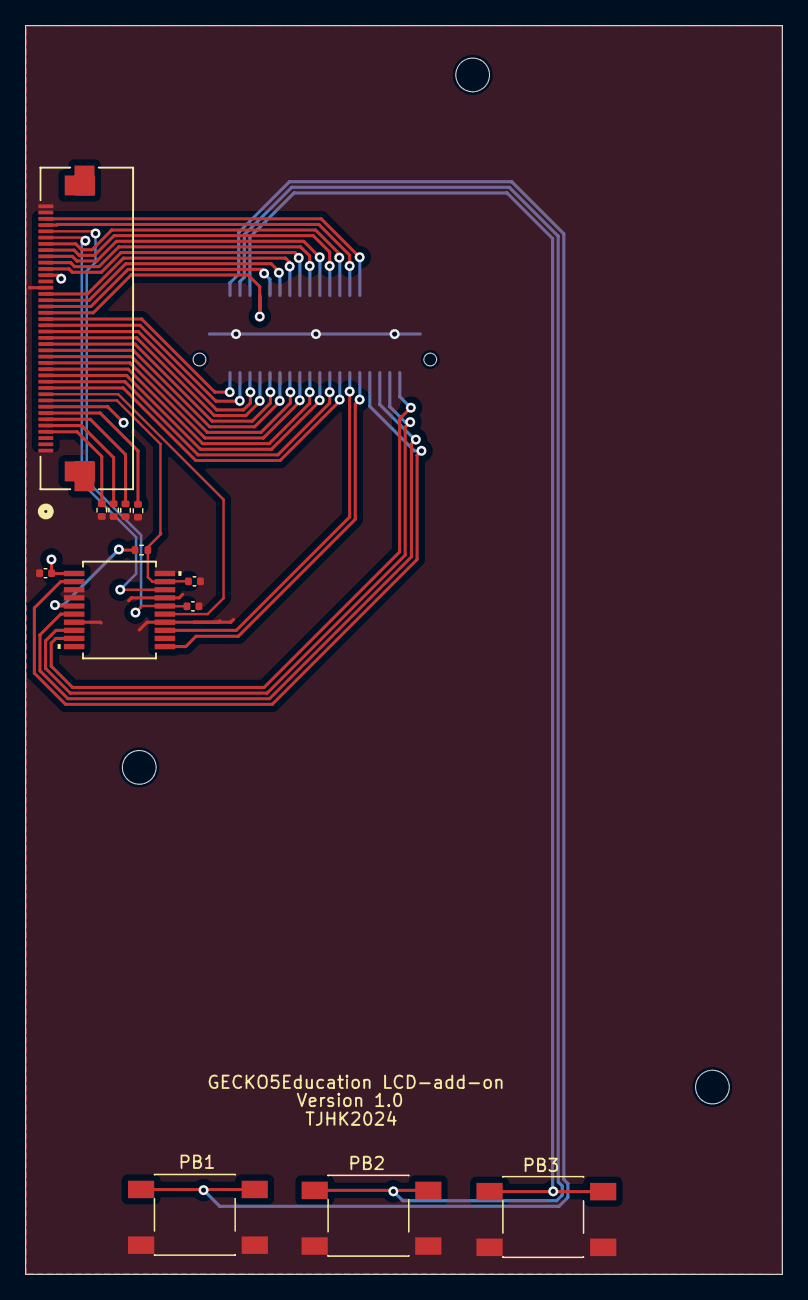
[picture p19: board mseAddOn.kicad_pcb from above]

Board: 2 copper layers, 60.6 x 100.0 mm, 14 parts (1 on the bottom side), 43 nets.

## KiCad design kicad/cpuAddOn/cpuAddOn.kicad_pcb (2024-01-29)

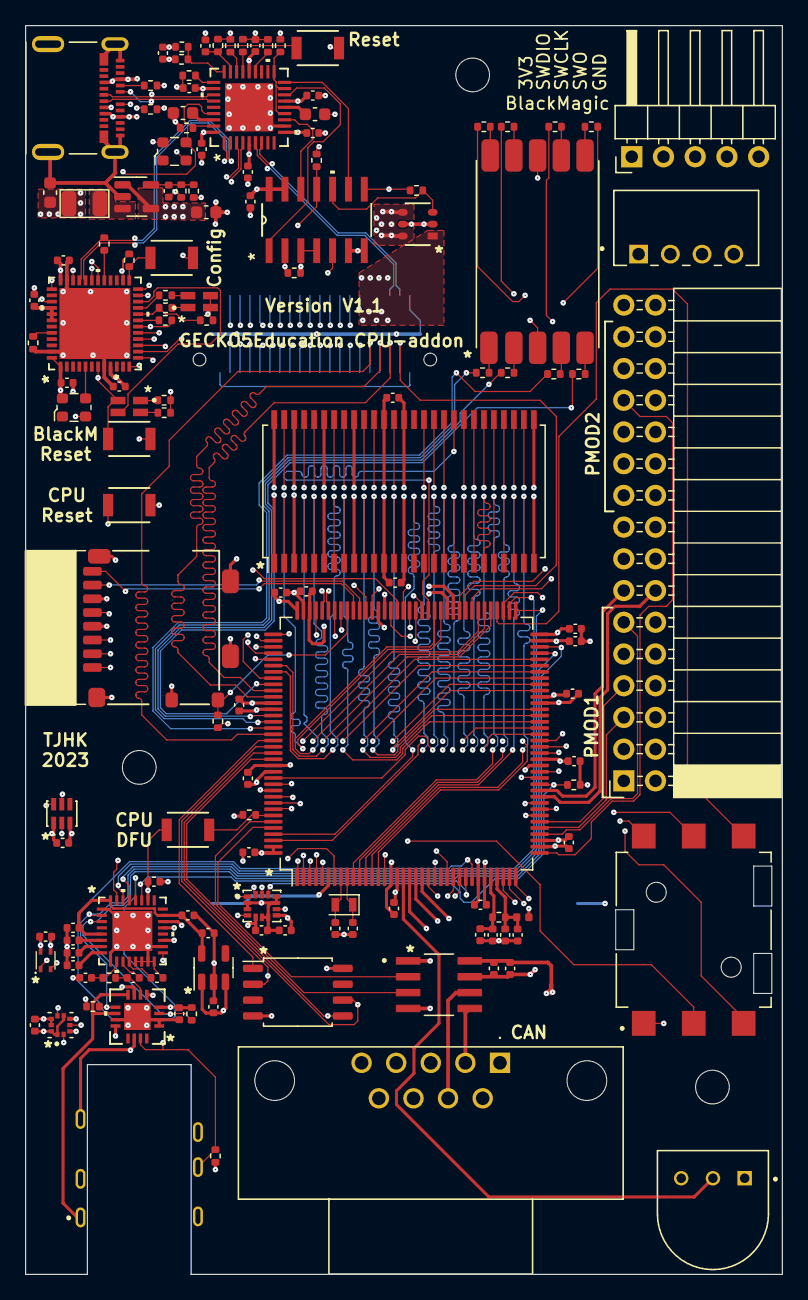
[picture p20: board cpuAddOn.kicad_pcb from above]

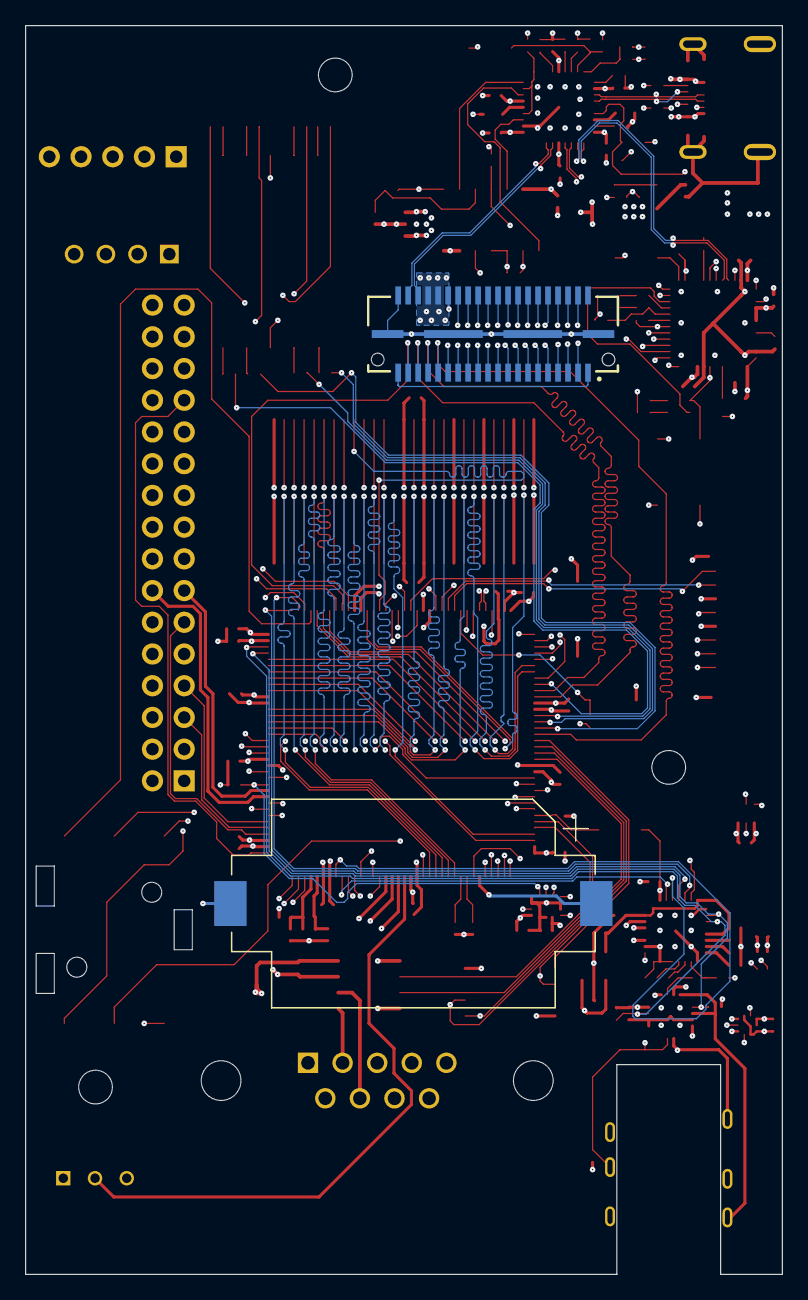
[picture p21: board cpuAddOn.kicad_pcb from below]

Board: 6 copper layers, 60.6 x 100.0 mm, 138 parts (2 on the bottom side), 191 nets.

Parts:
A1: LPS22HBTR; PQFN50P200X200X80-10N
BT1: Battery_Cell; BatteryHolder_Keystone_1060_1x2032
C1, C3, C4, C5: C1608X5R0J106M080AB; C_0603_1608Metric
C2: 18p; C_0402_1005Metric
C6, C7, C8, C9, C10, C11, C12, C13, C14, C15, C16, C17, C18, C19, C20, C22, C33, C34, C35, C37, C38, C39, C42, C43, C44, C45, C46, C47, C48, C49, C50, C51, C52, C55: 100n; C_0402_1005Metric
C21, C23, C24, C25, C26, C29, C30, C32, C36, C53, C54: 1u; C_0402_1005Metric
C27, C28: 220n; C_0402_1005Metric
C31, C40, C41: 2u2; C_0402_1005Metric
C56, C57: 9pF; C_0402_1005Metric
D1, D2: APHBM2012SURKCGKC; LED_APHBM2012SURKCGKC
J1: QTE-020-01-X-D-A; SAMTEC_QTE-020-01-X-D-A
J2: 105450-0101; MOLEX_105450-0101
J3: Conn_01x05_Pin; PinHeader_1x05_P2.54mm_Horizontal
J4: SJ-3551B-MSMT-TR-67; CUI_SJ-3551B-MSMT-TR-67
J5: TE_2311765-1
J7: Conn_02x16_Odd_Even; PinSocket_2x16_P2.54mm_Horizontal
L1: LQM2HPN2R2MJ0L
L2: 1k @ 100MHz; L_0402_1005Metric
PS1: B0505S-1WR3; CONV_B0505S-1WR2
R1, R2: 5k1; R_0402_1005Metric
R3, R4, R7: 100k; R_0402_1005Metric
R5: 680k; R_0402_1005Metric
R6: 150k; R_0402_1005Metric
R8: 12k; R_0402_1005Metric
R9, R10, R11, R12, R13, R15, R16, R17, R18, R21, R24, R25, R26, R28, R30, R31, R32, R33: 10k; R_0402_1005Metric
R14: 1k5; R_0402_1005Metric
R19, R22: 768R; R_0402_1005Metric
R20, R23: 330R; R_0402_1005Metric
R27: 3352T-1-103LF; TRIM_3352T-1-103LF
R29: 2k2; R_0402_1005Metric
R34: 47E; R_0402_1005Metric
R35, R36, R37, R38, R39, R40, R41, R42: 62R; R_0402_1005Metric
S1: JS5208
SD1: 104031-0811; sdcard
SW1, SW2, SW3, SW4, SW5: B3U-1000P[]; SW_B3U-1000P_OMR
U1: USB2513B-AEZC; QFN36_6X6MC_MCH
U2: NCP1529A; SOT-23-5
U3: STM32F103CBU6; UFQFPN-48_7X7X0P55MM
U4: SN74HC266DR; D14
U5: AP2281-3WG-7; SOT26_DIO
U6: STM32H743ZITx; LQFP-144_20x20mm_P0.5mm
U7: AS4C16M16SA-6TAN; TSOP-II-54_22.2x10.16mm_P0.8mm
U8: ISO1044BD; SOIC127P599X175-8N
U9: TS3A227ERVAR; RVA16_2P14X2P14_TEX
U10: MAX9867ETJ+; 21-0140L_T3255-4_MXM
U11: LP5907MFX-1.8; SOT-23-5
U12: MX25R3235FM2IL0; SOP-8_5.28x5.23mm_P1.27mm
U13: ICM-42605; PQFN50P300X250X97-14N
U14: SHT40-AD1B-R2; SHT4X
U15: TCS34003FNM; SON65P200X240X70-6N
U16: HDSM-433C; HDSM-431W
X1: ECS-2520MV-240-BL-TR; Oscillator_SMD_ECS_2520MV-xxx-xx-4Pin_2.5x2.0mm
X2: ECS-2520MV-080-BM-TR; Oscillator_SMD_ECS_2520MV-xxx-xx-4Pin_2.5x2.0mm
Y1: RT2012-32.768-9-20-EXT-TR; Crystal_SMD_2012-2Pin_2.0x1.2mm

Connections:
+1V8: C24.1, C32.1, C34.1, U10.5 (AVDD), U10.23 (PVDD), U10.32 (DVDD), U11.5 (OUT)
+3.3V: A1.1 (VDD_IO), A1.6 (CS), A1.10 (VDD), C2.1, C3.1, C8.1, C9.1, C10.1, C11.1, C12.1, C13.1, C14.1, C15.1, C16.1, C17.1, C18.1, C19.1, C20.1, C23.1, C25.1, C33.1, C35.1, C36.1, C37.1, C38.1, C39.1, C42.1, C43.1, C44.1, C45.1, C46.1, C47.1, C48.1, C49.1, C50.1, C51.1, J3.1, J7.1, J7.2, J7.19, J7.20, L1.2, L2.2, R5.1, R7.2, R10.1, R13.2, R15.2, R16.1, R17.1, R22.1, R23.1, R24.1, R25.2, R26.1, R27.3, R28.1, R30.1, R31.2, SD1.4 (VCC), SW5.2, U1.5 (VDDA33), U1.10 (VDDA33), U1.15 (VDD33), U1.23 (VDD33), U1.29 (VDDA33), U1.36 (VDD33), U3.1 (VBAT), U3.9 (VCCA), U3.18 (PB0), U3.24 (VCCB), U3.26 (PB13), U3.36 (VCCC), U3.40 (PB4), U3.41 (PB5), U3.42 (PB6), U3.48 (VCCD), U4.2 (1B), U4.8 (3A), U4.13 (4B), U4.14 (VCC), U6.17 (VDD), U6.30 (VDD), U6.39 (VDD), U6.52 (VDD), U6.62 (VDD), U6.72 (VDD), U6.84 (VDD), U6.95 (VDD33_USB), U6.108 (VDD), U6.121 (VDD), U6.131 (VDD), U6.143 (PDR_ON), U6.144 (VDD), U7.1 (VDD), U7.3 (VDDQ), U7.9 (VDDQ), U7.14 (VDD), U7.27 (VDD), U7.43 (VDDQ), U7.49 (VDDQ), U8.1 (VCC1), U9.4 (VDD), U10.26 (DVDDIO), U11.1 (IN), U11.3 (EN), U12.8 (VCC), U13.5 (VDDIO), U13.8 (VDD), U14.3 (VDD), U15.1 (VDD), X1.4 (VDD), X2.4 (VDD)
+5V: C1.1, C6.1, J2.A4 (VBUS1), J2.A9 (VBUS2), J2.B4 (VBUS3), J2.B9 (VBUS4), PS1.2 (VIN), R4.2, U2.1 (EN), U2.4 (VIN), U5.4 (IN), U5.6 (IN)
/BlackMagicProbe/SWCLK: J3.3, U3.37 (SWCLK)
/BlackMagicProbe/SWDIO: J3.2, U3.34 (SWIO)
/BlackMagicProbe/SWO: J3.4, U3.39 (PB3)
ADC4: J7.17, U6.19 (PF7)
ADC_PWM0: J7.14, U6.46 (PB0)
ADC_PWM1: J7.13, U6.47 (PB1)
ADC_PWM2: J7.16, U6.20 (PF8)
ADC_PWM3: J7.15, U6.21 (PF9)
BlackCpuReset: U3.12 (PA2), U4.5 (2A)
BlackD+: R14.1, U1.2 (USBDP_DN1/PRT_DIS_P1), U3.33 (PA12)
BlackD-: U1.1 (USBDM_DN1/PRT_DIS_M1), U3.32 (PA11)
BlackRxd: U3.30 (PA9), U6.102 (PA10)
BlackTxd: U3.31 (PA10), U6.101 (PA9)
BlacknReset: D2.2, R16.2, SW2.1, U3.7 (NRST), U4.11 (4Y)
BlacknResetDrive: U1.12 (PRTPWR1/BC_EN1), U4.12 (4A)
CPUnReset: R15.1, SW4.1, U3.17 (PA7), U4.3 (1Y), U4.4 (2Y), U6.25 (NRST)
CPUnResetDrive: U1.16 (PRTPWR2/BC_EN2), U4.1 (1A)
CanRxd: U6.139 (PB8), U8.3 (Rxd)
CanTxd: U6.140 (PB9), U8.2 (TxD)
Clock24MHz: U1.33 (XTALIN/CLKIN), U6.23 (PH0), U10.31 (MCLK), X1.3 (OUT)
CodecBclk: U6.74 (PB13), U10.30 (BCLK)
CodecLRclk: U6.73 (PB12), U10.29 (LRCLK)
CodecSDin: U6.29 (PC3_C), U10.28 (SDIN)
CodecSDout: U6.28 (PC2_C), U10.27 (SDOUT)
Color_Int: U6.92 (PG7), U15.5 (INT)
CpuD+: U1.4 (USBDP_DN2/PRT_DIS_P2), U6.104 (PA12)
CpuD-: U1.3 (USBDM_DN2/PRT_DIS_M2), U6.103 (PA11)
CpuTckSwclk: U3.15 (PA5), U6.109 (PA14)
CpuTdi: U3.13 (PA3), U6.110 (PA15)
CpuTdoSwo: U3.16 (PA6), U6.133 (PB3)
CpuTmsSwdio: U3.14 (PA4), U6.105 (PA13)
D1+: J2.A6 (D1+), J2.B6 (D2+), U1.31 (USBDP_UP)
D1-: J2.A7 (D1-), J2.B7 (D2-), U1.30 (USBDM_UP)
EnFPGA: R17.2, U4.10 (3Y), U5.3 (EN)
FMC_A0: J1.24, U6.10 (PF0), U7.23 (A0)
FMC_A1: J1.26, U6.11 (PF1), U7.24 (A1)
FMC_A2: J1.28, U6.12 (PF2), U7.25 (A2)
FMC_A3: J1.30, U6.13 (PF3), U7.26 (A3)
FMC_A4: J1.29, U6.14 (PF4), U7.29 (A4)
FMC_A5: J1.27, U6.15 (PF5), U7.30 (A5)
FMC_A6: J1.25, U6.50 (PF12), U7.31 (A6)
FMC_A7: J1.23, U6.53 (PF13), U7.32 (A7)
FMC_A8: J1.21, U6.54 (PF14), U7.33 (A8)
FMC_A9: J1.20, U6.55 (PF15), U7.34 (A9)
FMC_A10: J1.22, U6.56 (PG0), U7.22 (A10/AP)
FMC_A11: J1.19, U6.57 (PG1), U7.35 (A11)
FMC_A12: U6.87 (PG2), U7.36 (A12)
FMC_BA0: U6.89 (PG4), U7.20 (BA0)
FMC_BA1: U6.90 (PG5), U7.21 (BA1)
FMC_CKE: U6.45 (PC5), U7.37 (CKE)
FMC_CLK: U6.93 (PG8), U7.38 (CLK)
FMC_D0: J1.03, U6.85 (PD14), U7.2 (DQ0)
FMC_D1: J1.05, U6.86 (PD15), U7.4 (DQ1)
FMC_D2: J1.07, U6.114 (PD0), U7.5 (DQ2)
FMC_D3: J1.09, U6.115 (PD1), U7.7 (DQ3)
FMC_D4: J1.11, U6.58 (PE7), U7.8 (DQ4)
FMC_D5: J1.13, U6.59 (PE8), U7.10 (DQ5)
FMC_D6: J1.15, U6.60 (PE9), U7.11 (DQ6)
FMC_D7: J1.17, U6.63 (PE10), U7.13 (DQ7)
FMC_D8: J1.18, U6.64 (PE11), U7.42 (DQ8)
FMC_D9: J1.16, U6.65 (PE12), U7.44 (DQ9)
FMC_D10: J1.14, U6.66 (PE13), U7.45 (DQ10)
FMC_D11: J1.12, U6.67 (PE14), U7.47 (DQ11)
FMC_D12: J1.10, U6.68 (PE15), U7.48 (DQ12)
FMC_D13: J1.08, U6.77 (PD8), U7.50 (DQ13)
FMC_D14: J1.06, U6.78 (PD9), U7.51 (DQ14)
FMC_D15: J1.04, U6.79 (PD10), U7.53 (DQ15)
FMC_DQM0: U6.141 (PE0), U7.15 (LDQM)
FMC_DQM1: U6.142 (PE1), U7.39 (UDQM)
FMC_nCAS: U6.132 (PG15), U7.17 (~CAS)
FMC_nCS: U6.44 (PC4), U7.19 (~CS)
FMC_nRAS: U6.49 (PF11), U7.18 (~RAS)
FMC_nWE: U6.43 (PA7), U7.16 (~WE)
FPGADrive: U1.18 (PRTPWR3/BC_EN3), U4.9 (3B)
FPGA_IRQ: J1.37, U6.81 (PD12)
FPGA_nCS: J1.31, U6.125 (PG10)
FPGA_nOE: J1.35, U6.118 (PD4)
FPGA_nWE: J1.33, U6.119 (PD5)
GND: A1.3 (RESERVED), A1.5 (SDO/SA0), A1.8 (GND), A1.9 (GND), BT1.2 (-), C1.2, C3.2, C4.2, C5.2, C6.2, C7.2, C8.2, C9.2, C10.2, C11.2, C12.2, C13.2, C14.2, C15.2, C16.2, C17.2, C18.2, C19.2, C20.2, C23.2, C24.2, C25.2, C26.1, C28.2, C29.2, C30.2, C31.2, C32.2, C33.2, C34.2, C35.2, C36.2, C37.2, C38.2, C39.2, C40.2, C41.2, C42.2, C43.2, C44.2, C45.2, C46.2, C47.2, C48.2, C49.2, C50.2, C51.2, C52.2, C53.2, C54.2, C55.2, C56.2, C57.2, D1.2, D1.3, J1.40, J1.G1 (GND), J1.G2 (GND), J1.G3 (GND), J1.G4 (GND), J2.A1 (GND1), J2.A12 (GND2), J2.B1 (GND3), J2.B12 (GND4), J2.S1 (SHIELD), J2.S2 (SHIELD), J2.S3 (SHIELD), J2.S4 (SHIELD), J3.5, J4.6, J7.3, J7.4, J7.18, J7.21, J7.22, J7.31, PS1.1 (GND), R1.1, R2.1, R3.1, R6.2, R8.1, R9.1, R11.1, R12.1, R18.1, R21.1, R27.1, R32.2, R33.1, S1.1, SD1.6 (GND), SD1.GM1 (GND), SD1.GM2 (GND), SD1.GM3 (GND), SD1.GM4 (GND), SD1.GS4 (GND), SW1.2, SW2.2, SW3.2, SW4.2, U1.11 (TEST), U1.37 (EPAD), U2.2 (GND), U3.8 (GNDA), U3.23 (GNDB), U3.35 (GNDC), U3.47 (GNDD), U3.49 (EPAD), U4.6 (2B), U4.7 (GND), U5.2 (GND), U5.5 (GND), U6.16 (VSS), U6.31 (VSSA), U6.38 (VSS), U6.51 (VSS), U6.61 (VSS), U6.83 (VSS), U6.94 (VSS), U6.107 (VSS), U6.120 (VSS), U6.130 (VSS), U7.6 (VSSQ), U7.12 (VSSQ), U7.28 (VSS), U7.41 (VSS), U7.46 (VSSQ), U7.52 (VSSQ), U7.54 (VSS), U8.4 (GND1), U9.1 (GND), U9.2 (GND), U9.11 (GNDA), U9.17 (EPAD), U10.1 (DGND), U10.9 (AGND), U10.13 (MICRP), U10.14 (MICRN), U10.15 (LINL), U10.16 (LINR), U10.18 (PGND), U10.33 (EPAD), U11.2 (GND), U12.4 (GND), U13.2 (RESV_1), U13.3 (RESV_2), U13.6 (GND), U13.7 (RESV_3), U13.10 (RESV_4), U13.11 (RESV_5), U14.4 (VSS), U15.3 (GND), U16.3 (CC), U16.8 (CC), X1.2 (GND), X2.2 (GND)
Joy2: S1.2, U6.134 (PB4)
Joy3: S1.3, U6.1 (PE2)
Joy4: S1.4, U6.2 (PE3)
Joy5: S1.5, U6.3 (PE4)
Joy6: S1.6, U6.76 (PB15)
Motion_Int1: U6.88 (PG3), U13.4 (INT1/INT)
Motion_Int2: U6.75 (PB14), U13.9 (INT2/FSYNC)
Motion_nCS: R32.1, U6.48 (PB2), U13.12 (AP_CS)
unnamed: BT1.1 (+), J7.32, U6.6 (VBAT)
unnamed: C40.1, C41.1, U6.71 (VCAP), U6.106 (VCAP)
unnamed: D1.1, R19.1
unnamed: D1.4, R20.1
unnamed: D2.1, R22.2
unnamed: D2.4, R23.2
unnamed: J1.01, J1.39
unnamed: J2.A5 (CC1), R1.2
unnamed: J2.B5 (CC2), R2.2
unnamed: C21.2, C22.2, PS1.3 (0V), U8.7 (GND2)
unnamed: C21.1, C22.1, PS1.4 (+VO), U8.8 (VCC2)
unnamed: C5.1, U1.14 (CRFILT)
unnamed: R10.2, U1.25 (HS_IND/CFG_SEL1)
unnamed: R25.1, U1.13 (OCS_N1), U1.17 (OCS_N2), U1.19 (OCS_N3)
unnamed: C4.1, U1.34 (PLLFILT)
unnamed: R8.2, U1.35 (RBIAS)
unnamed: C7.1, R7.1, SW3.1, U1.26 (RESET_N)
unnamed: R11.2, U1.24 (SCL/SMBCLK/CFG_SEL0)
unnamed: R12.2, U1.22 (SDA/SMBDATA/NON_REM1)
unnamed: R9.2, U1.28 (SUSP_IND/LOCAL_PWR/NON_REM0)
unnamed: R3.2, R4.1, U1.27 (VBUS_DET)
unnamed: C2.2, R5.2, R6.1, U2.5 (FB)
unnamed: L1.1, U2.3 (SW)
unnamed: R18.2, U3.44 (BOOT0)
unnamed: U3.5 (OSCIN), X2.3 (OUT)
unnamed: R14.2, U3.29 (PA8)
unnamed: R13.1, U3.19 (PB1)
unnamed: R19.2, R21.2, U3.20 (PB2/BOOT1)
unnamed: R20.2, U3.21 (PB10)
unnamed: D2.3, U3.22 (PB11)
unnamed: R24.2, SW1.1, U3.25 (PB12)
unnamed: J1.32, J1.34, U5.1 (OUT)
unnamed: R33.2, SW5.1, U6.138 (BOOT0)
unnamed: C56.1, U6.8 (PC14), Y1.2
unnamed: C57.1, U6.9 (PC15), Y1.1
unnamed: R27.2, U6.18 (PF6)
unnamed: C54.1, C55.1, L2.1, R34.1, U6.33 (VDDA)
unnamed: C52.1, C53.1, R34.2, U6.32 (VREF+)
unnamed: J5.7, U8.6 (CANH)
unnamed: J5.2, U8.5 (CANL)
unnamed: C27.1, R29.1, U9.6 (MICP)
unnamed: J4.4, U9.7 (RING2_SENSE), U9.12 (RING2)
unnamed: J4.1, U9.8 (SLEEVE_SENSE), U9.10 (SLEEVE)
unnamed: J4.5, R28.2, U9.15 (*DET_TRIGGER), U10.17 (JACKSNS/AUX)
unnamed: U9.5 (GND_SENSE), U10.21 (LOUTN)
unnamed: J4.2, U9.14 (TIP), U10.22 (LOUTP)
unnamed: C26.2, R29.2, U10.10 (MICBIAS)
unnamed: C27.2, U10.11 (MICLN/DIGMICCLK)
unnamed: C28.1, U10.12 (MICLP/DIGMICDATA)
unnamed: C30.1, U10.7 (PREG)
unnamed: C31.1, U10.6 (REF)
unnamed: C29.1, U10.8 (REG)
unnamed: J4.3, U10.19 (ROUTP)
unnamed: R35.2, U16.7 (A)
unnamed: R36.2, U16.6 (B)
unnamed: R37.2, U16.4 (C)
unnamed: R38.2, U16.2 (D)
unnamed: R42.2, U16.5 (DP)
unnamed: R39.2, U16.1 (E)
unnamed: R40.2, U16.9 (F)
unnamed: R41.2, U16.10 (G)
PMOD1_1: J7.11, U6.40 (PA4)
PMOD1_2: J7.9, U6.135 (PB5)
PMOD1_3: J7.7, U6.42 (PA6)
PMOD1_4: J7.5, U6.41 (PA5)
PMOD1_7: J7.12, U6.4 (PE5)
PMOD1_8: J7.10, U6.5 (PE6)
PMOD1_9: J7.8, U6.136 (PB6)
PMOD1_10: J7.6, U6.137 (PB7)
PMOD2_1: J7.29, U6.34 (PA0)
PMOD2_2: J7.27, U6.36 (PA2)
PMOD2_3: J7.25, U6.37 (PA3)
PMOD2_4: J7.23, U6.35 (PA1)
PMOD2_7: J7.30, U6.7 (PC13)
PMOD2_8: J7.28, U6.27 (PC1)
PMOD2_9: J7.26, U6.26 (PC0)
PMOD2_10: J7.24, U6.22 (PF10)
Presure_Irq: A1.7 (INT_DRDY), U6.91 (PG6)
SCL: A1.2 (SCL/SPC), R31.1, U6.69 (PB10), U9.9 (SCL), U10.2 (SCL), U14.2 (SCL), U15.2 (SCL)
SDA: A1.4 (SDA/SDI/SDO), R30.2, U6.70 (PB11), U9.3 (SDA), U10.3 (SDA), U14.1 (SDA), U15.6 (SDA)
SD_CLK: SD1.5 (CLK), U6.113 (PC12)
SD_CMD: SD1.3 (CMD), U6.116 (PD2)
SD_D0: SD1.7 (DAT0), U6.98 (PC8)
SD_D1: SD1.8 (DAT1), U6.99 (PC9)
SD_D2: SD1.1 (DAT2), U6.111 (PC10)
SD_D3: SD1.2 (CD/DAT3), U6.112 (PC11)
SD_nDET: R26.2, SD1.10 (SW-2), U6.100 (PA8)
Seg_A: R35.1, U6.80 (PD11)
Seg_B: R36.1, U6.82 (PD13)
Seg_C: R37.1, U6.124 (PG9)
Seg_D: R38.1, U6.122 (PD6)
Seg_DP: R42.1, U6.117 (PD3)
Seg_E: R39.1, U6.123 (PD7)
Seg_F: R40.1, U6.97 (PC7)
Seg_G: R41.1, U6.96 (PC6)
USERF_SCLK: U6.128 (PG13), U12.6 (SCLK), U13.13 (AP_SCL/AP_SCLK)
USERF_SI: U6.129 (PG14), U12.5 (SI/SIO0), U13.14 (AP_SDA/AP_SDIO/AP_SDI)
USERF_SO: U6.127 (PG12), U12.2 (SO/SIO1), U13.1 (AP_SDO/AP_ADO)
USERF_nCS: U6.126 (PG11), U12.1 (~CS)
UsbD+: J1.38, U1.7 (USBDP_DN3/PRT_DIS_P3)
UsbD-: J1.36, U1.6 (USBDM_DN3/PRT_DIS_M3)

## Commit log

2023-06-18 Added kicad files
    [1054500101.stp, 7 segment1.STEP, ECS-2520MV-500-BL-TR--3DModel-STEP-269445.STEP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]
2023-06-18 Added 3D model for the SD-card reader
    [104031-0811.stp]
2023-06-18 Removed the nDet from the SD-card and added the 12 MHz oscillator as clock input to be fully compatible with the GECKO4 clock inputs
    [gecko5education.ods, led_array.kicad_sch, pmod.kicad_sch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]
2023-07-04 Added an USB-switch and mountig holes for better connection of add-on cards. Created a template for add-on cards.
    [104031-0811.stp, 1054500101.stp, 7 segment1.STEP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]
2023-07-19 Added add-on board template. Added a CPU-add-on board.
    [104031-0811.stp, 105450-0101.step, 21-0140L_T3255-4_MXM.step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]
2023-07-24 Small revision on PCB
    [cpuAddOn.kicad_pcb]
2023-08-07 fixed bug with RS232 Added support for bigger SDRAMs Changed 7-segment display to SMD and active low
    [cpu.kicad_sch, cpuAddOn.kicad_pcb, cpuAddOn.ods]
2023-08-10 Made V1.1 of the cpu-addon
    [HDSM-431W.stp, cpu.kicad_sch, cpuAddOn.kicad_pcb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]
2023-09-10 Small modifications plus added documentation
    [CB3LV-3I-74M2500.step, extconn.ods, gecko5education.ods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]
2023-09-27 Made version V1.5
    [gecko5education.ods, gpio.kicad_sch, hdmi.kicad_sch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]
2023-10-01 Made V1.6
    [ATSAMD51J20A-AU.STEP, LTC2632CTS8-LZ12#TRMPBF.STEP, MAX11666AUB_V+.STEP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]
2023-10-18 No changes
    [hdmi.kicad_sch]
2023-10-20 Updated price list
    [gecko5education.ods, hdmi.kicad_sch]
2023-10-20 First version
    [hdmi.kicad_sch]
2023-11-01 small progress
    [hdmi.kicad_sch, pmod.kicad_sch]
2023-11-03 Added SII9022
    [gecko5education.ods, hdmi.kicad_sch, pmod.kicad_sch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]
2023-11-03 small update on V1.4
    [gecko5education.ods, gpio.kicad_sch]
2023-12-07 Added 2 add-on boards and updated GECKO5 to support olimex camera-OV7670 and an RTC.
    [104031-0811.stp, 105450-0101.step, 21-0140L_T3255-4_MXM.step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]
2023-12-07 Added bom
    [perifAddOn.kicad_pcb, perifAddOn.ods]
2024-01-09 removed SII9022
    [hdmi.kicad_sch]
2024-01-09 Added chip
    [hdmi.kicad_sch]
2024-01-10 Final version
    [gecko5education.ods, gpio.kicad_sch, hdmi.kicad_sch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]
2024-01-29 latest version with camera
    [QTE-020-01-X-D-A.step, addOnTemplate.kicad_pcb, addOnTemplate.kicad_sch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]
2024-04-17 V1.1 of perifAddOn (added bus-switch on sd-card)
    [TSSOP20_z90.stp, addOnTemplate.kicad_pcb, cardReader.kicad_sch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]
2024-07-10 removed obsolete SII164 and replaced by TFP410
    [gecko5education.ods, hdmi.kicad_sch]
2025-03-22 Switched to less expensive RGB-Leds
    [gecko5education.ods, led_array.kicad_sch]
2025-07-10 Put faster ADC
    [gecko5education.ods]

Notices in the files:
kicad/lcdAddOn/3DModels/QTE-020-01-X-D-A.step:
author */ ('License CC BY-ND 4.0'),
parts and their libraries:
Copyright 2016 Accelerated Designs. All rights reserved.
